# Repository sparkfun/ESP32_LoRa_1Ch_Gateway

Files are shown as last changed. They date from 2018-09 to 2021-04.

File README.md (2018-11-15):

SparkFun LoRa Gateway 1-Channel
========================================

SparkFun LoRa Gateway 1-Channel

[*SparkFun LoRa Gateway 1-Channel (15006)*](https://www.sparkfun.com/products/15006)

A programmable microcontroller featuring both WiFi and Bluetooth radios -- with an RFM95W LoRa transceiver to create a single-channel LoRa gateway. It's a perfect, low-cost tool for monitoring a dozen-or-so LoRa devices, and relaying their messages up to the cloud.

Repository Contents
-------------------

* **/Documentation** - Data sheets, additional product information
* **/Firmware** - Example code 
* **/Hardware** - Eagle design files (.brd, .sch)

Documentation
--------------
* **[Library](https://github.com/sparkfun/ESP32_LoRa_1Ch_Gateway)** - Arduino library for the SparkFun LoRa Gateway 1-Channel.
* **[Hookup Guide](https://learn.sparkfun.com/tutorials/sparkfun-lora-gateway-1-channel-hookup-guide)** - Basic hookup guide for the SparkFun LoRa Gateway 1-Channel.
* **[SparkFun Fritzing repo](https://github.com/sparkfun/Fritzing_Parts)** - Fritzing diagrams for SparkFun products.

Product Versions
----------------
* [15006](https://www.sparkfun.com/products/15006) - SparkFun LoRa Gateway 1-Channel

Version History
---------------
* [v10](https://github.com/sparkfun/ESP32_LoRa_1Ch_Gateway/releases/tag/v10) - Initial redboard release

License Information
-------------------

This product is _**open source**_! 

Please review the LICENSE.md file for license information. 

If you have any questions or concerns on licensing, please contact techsupport@sparkfun.com.

Distributed as-is; no warranty is given.

- Your friends at SparkFun.

_<COLLABORATION CREDIT>_

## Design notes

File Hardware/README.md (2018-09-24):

SparkFun <PRODUCT NAME> Design Files
=====================================

The .sch and .brd files hare are Eagle CAD schematic and PCB design files from SparkFun Electronics.
A freeware version of Eagle can be found [here](http://www.cadsoftusa.com/download-eagle/freeware/).

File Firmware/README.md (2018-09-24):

Software directory contents
===========================

* **ESP-1CH-TTN-Device-ABP** -- Arduino example sketch implementing a single-channel LoRaWAN device with ABP activation.
	* Depends on the [Arduino-LMIC library](https://github.com/mcci-catena/arduino-lmic).
* **arduino-esp32** -- board.txt and pin-variant files to add the SparkX ESP32 LoRa 1-CH Gateway to the ESP32 Arduino core
	* Depends on the [Arduino Core for ESP32 WiFi chip](https://github.com/espressif/arduino-esp32)

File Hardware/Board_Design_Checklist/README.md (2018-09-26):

Design Review Checklist Python Module
=====================================

Original Author: Pete Lewis

Creation Date: 4/9/2015

Updated: 5/10/16

Description:
-------------
This is a little GUI (using Tkinter) intended to make reviewing a board design a bit easier and faster.
I have included the necessary modules and a batch file to make installation easier.
A bunch of helpful images are located [here](https://github.com/sparkfun/Engineering_Design_Rules_Checklist/tree/master/Board_Design_Checklist/doc_images)

Python GUI Installation:
---------------------
### Windows:

1. Install [Python 2.7.x](https://www.python.org/downloads/windows/) on your machine. At the top of this page is a link to the latest release. From there download [Windows x86 MSI installer](https://www.python.org/ftp/python/2.7.11/python-2.7.11.msi).

	1a. Note, It must be installed in the directory "c:\Python27\" for the batch file installation to work.
	
	1b. import _tkinter will fail with: "ImportError: DLL load failed: %1 is not a valid Win32 application." if you try to use the 64-bit version of Python.
2. The installer will give you the option to setup your environment variables. May as well select this. At the time of this writing, it doesn't work right, but it's still helpful.

	2a. Right click on the start menu and select the 'Control Panel'.

	2b. Searching for env will show you 'Edit the system environment variables', choose this.

	2c. Click 'Environment Variables...' at the bottom.

	2d. Double click on 'Path'.

	2e. You should see 'C:\Python27\' & 'C:\Python27\Scripts'. Append a trailing '&#92;' to Scripts to fix it.

2. Clone the [repo](https://github.com/sparkfun/Engineering_Design_Rules_Checklist).
3. Run the batch file named "Install_Modules.bat" from within the repo (Excel_Modules_Installation).
4. You will see a command prompt open up and a bunch of readout.
5. When it's done, you should have the three necessary modules installed.

### OS X:

1. Install Homebrew
	```ruby -e "$(curl -fsSL https://raw.githubusercontent.com/Homebrew/install/master/install)"```
2. Install Python
	```brew install python```
3. Install pip
	```sudo easy_install pip```
4. Install Excel Modules
	```
	sudo pip install xlrd
	
	sudo pip install xlwt
	
	sudo pip install xlutils
	```
5. Clone the [repo](https://github.com/sparkfun/Engineering_Design_Rules_Checklist).
	
### Debian/Ubuntu: 

1. Install Python
	```
	sudo apt-get install python
	```
2. Install Excel Modules
	```
	sudo apt-get install python-xlrd
	
	sudo apt-get install python-xlwt
	
	sudo apt-get install python-pip
	
	sudo pip install xlutils
	```
	
### Generic Install Directions:

1. Install [Python 2.7.x](https://www.python.org/ftp/python/2.7.9/python-2.7.9.msi) on your machine.
2. Download and install the following modules.
  * [XLRD](https://pypi.python.org/pypi/xlrd)
  * [XLWT](https://pypi.python.org/pypi/xlwt)
  * [XLUTILS](https://pypi.python.org/pypi/xlutils)

You can do this with pip, for instance, run the command `pip install xlrd` to install XLRD

Running the Checklist:
----------------------
Run Checklist.py file from a directory that contains the original file `Board_Design_Checklist.xls`, or from a directory that contains an already started product specific `.xls` file.

The python file has two modes of operation:
1. If no `.xls` file exist, the program exits.
2. If an `.xls` file exists and is named `Board_Design_Checklist.xls`, the program will generate a new `.xls` file with the product name appended, such as `Board_Design_Checklist_fancynewproduct_.xls`.  The original spreadsheet is left intact.
3. If there is already a spreadsheet with product name appended, the program will open it for continuation or review.

You can double-click Checklist.py, or run from the command line as `>Checklist.py`

For example, if `folder` contains `Board_Design_Checklist.xls`: 
```
c:\>cd folder

c:\folder>dir
 Directory of c:\folder

06/14/2017  09:31 AM            25,600 Board_Design_Checklist.xls
06/14/2017  09:31 AM            18,827 Checklist.py

c:\folder>Checklist.py
Current User is marshall.taylor
Current Review File is Board_Design_Checklist.xls

c:\folder>dir
 Directory of c:\temp

06/14/2017  09:31 AM            25,600 Board_Design_Checklist.xls
06/15/2017  04:06 PM            22,016 Board_Design_Checklist_fancynewproduct_.xls
06/14/2017  09:31 AM            18,827 Checklist.py

c:\folder>
```

The first screen is a combination of checks. Check all of the boxes that apply to your design. This will help the GUI avoid asking you unnecessary checks.  The name entered here will be appended to the spreadsheet.

The next screens will prompt you all of the questions in the Excel doc (one at a time), and you can click "YES", "NO", "n/a", "back" or "skip".  It will then write to the appropriate cell in the XLS file and put your response (and username).

You can write a comment in the comment box before you click a button, and it will add this comment to your response in the appropriate cell in the Excel doc.

Once you get to the end, click the "Create Summary" button (at the bottom right of the GUI), if you'd like it to create a summary in the form of a text file including all of your responses with comments.

**You must put a comment with any answer if you'd like to it end up in the summary.**

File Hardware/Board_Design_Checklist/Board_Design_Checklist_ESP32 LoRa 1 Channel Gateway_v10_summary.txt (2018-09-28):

1) Have you verified that the BOM in Sparkle is accurate (also checking for PROD_ID, NAME, VALUE, PREFIX)? [NO]
comment: No, I haven't created a sparkle page for this product yet. It will probably be a clone of the SparkX version. 

2) Is the I2C address in the schematic? [n/a]
comment: N/A - this is an I2C master

3) Is the I2C pin order correct (GND/VCC/SDA/CLK) and did you consider using a Qwiic connector? [YES]
comment: Qwiic connector used

4) Is the I2C pull-up resistor isolation jumper present? [NO]
comment: No, this is a master. All downstream devices will have isolation option. Discussed with Nate

5) Is the SPI pull-up resistor for Chip Select present? [NO]
comment: No. There could be a CS PU on the RFM_CS net but this board is so jam-packed and that line is not broken out so I'm comfortable leaving it up to the ESP to push/pull that line

6) Are active low pins labeled clearly? [NO]
comment: RST is not, but this board is very tight

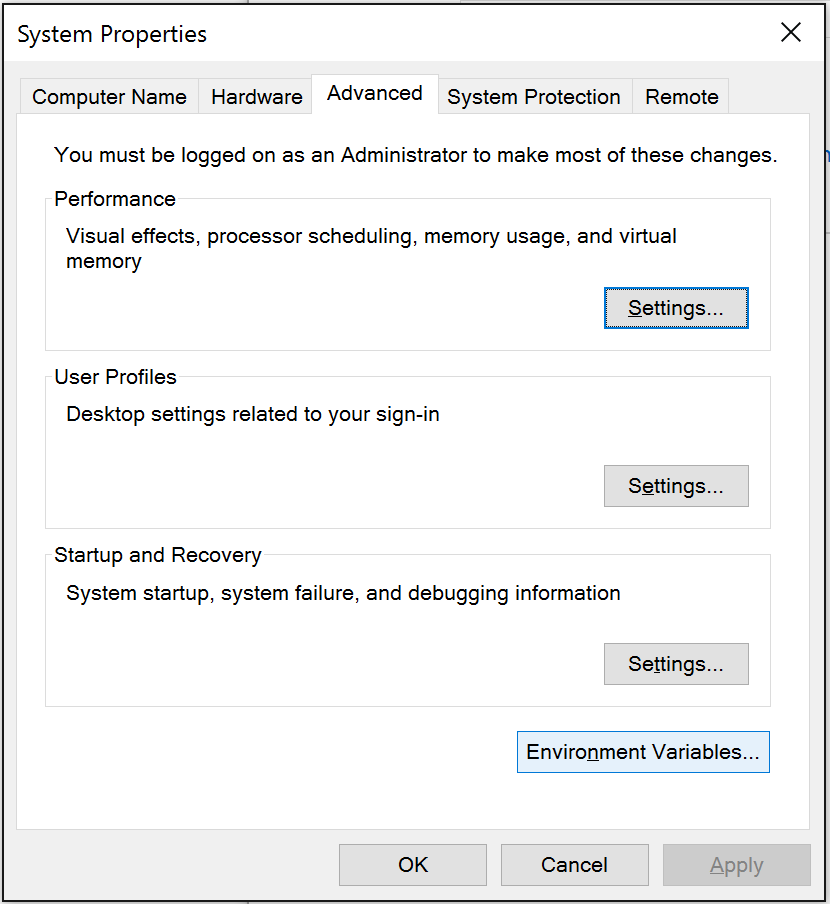
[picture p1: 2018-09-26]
Hardware/Board_Design_Checklist/doc_images/07-env_variables.png

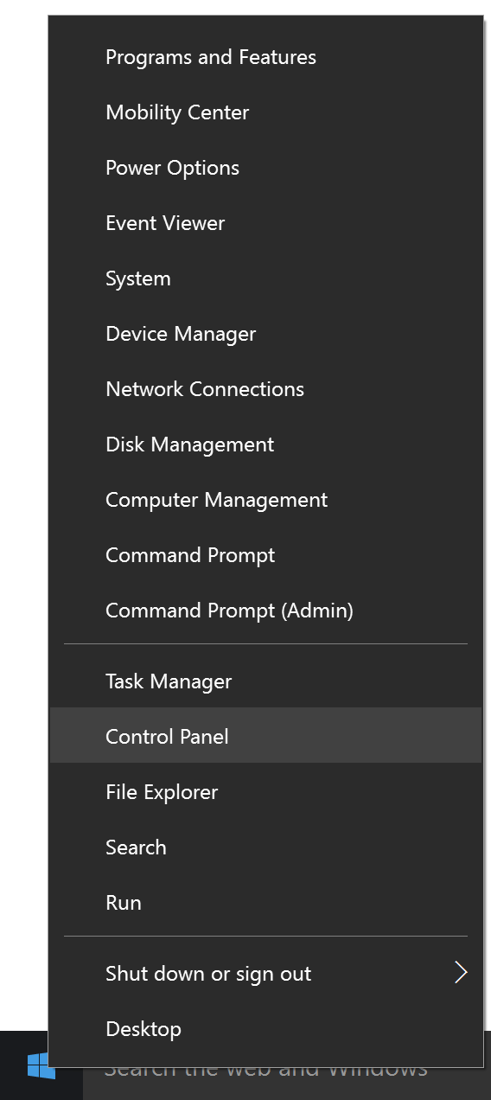
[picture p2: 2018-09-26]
Hardware/Board_Design_Checklist/doc_images/05-control_panel.png

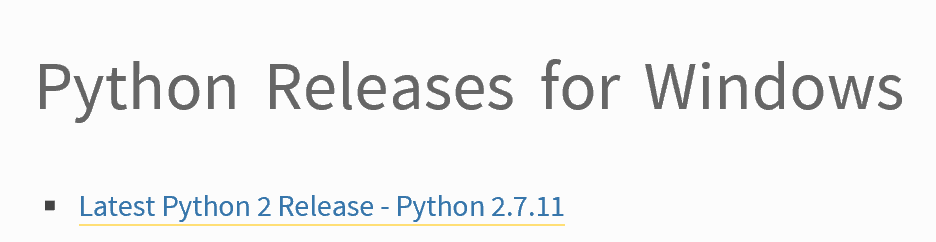
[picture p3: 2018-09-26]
Hardware/Board_Design_Checklist/doc_images/01-link.png

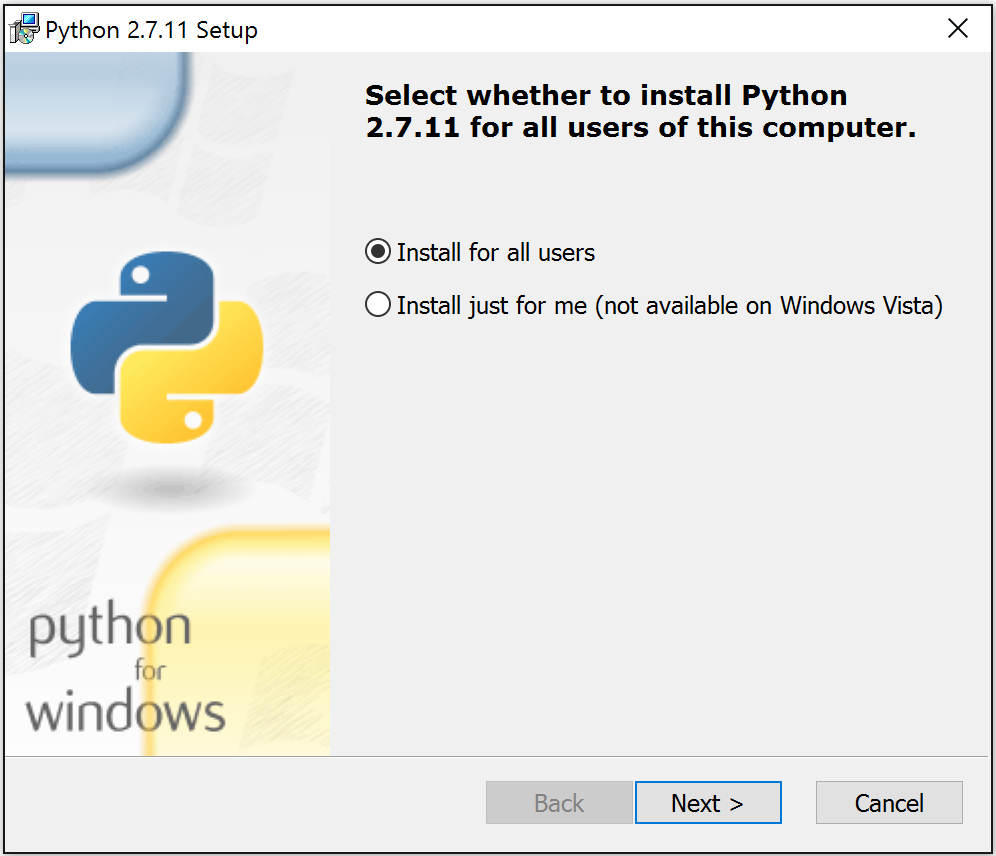
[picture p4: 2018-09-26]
Hardware/Board_Design_Checklist/doc_images/02-who.png

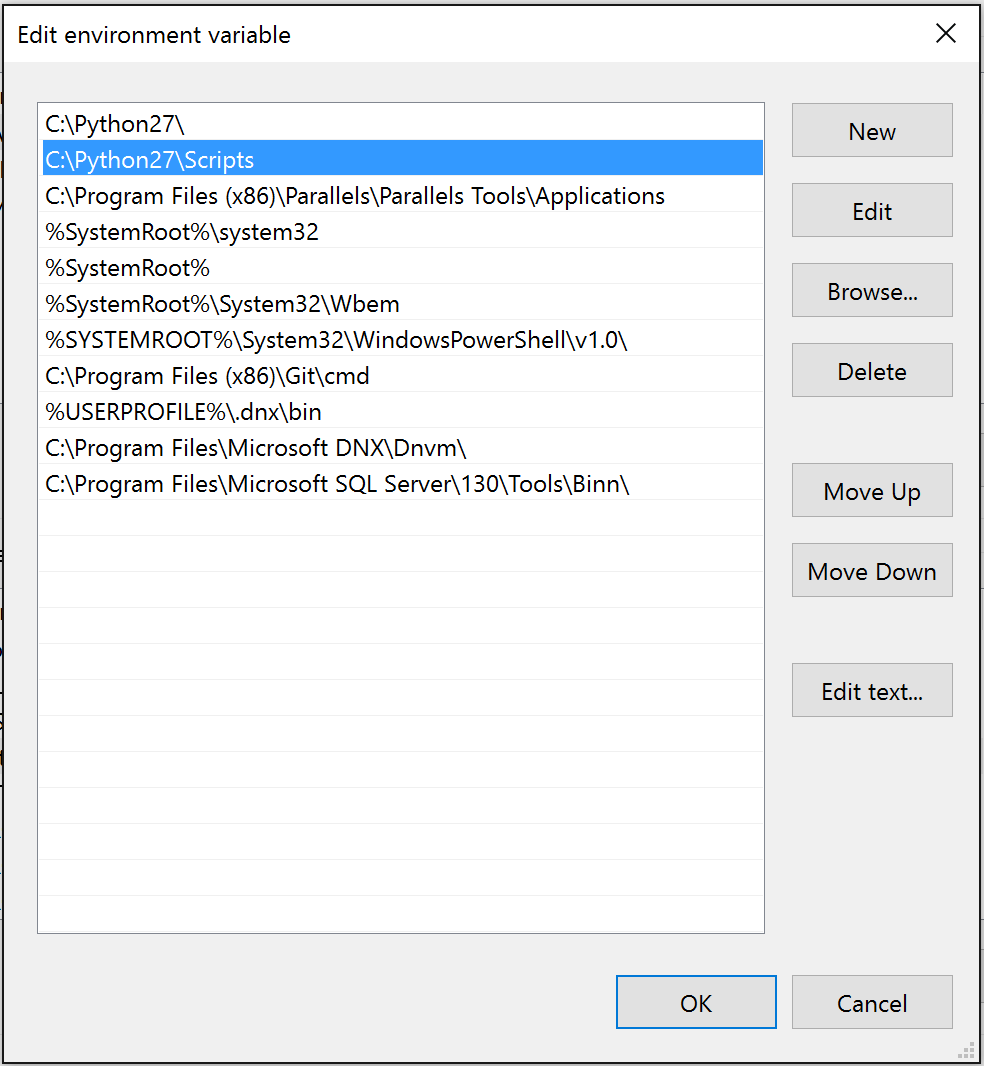
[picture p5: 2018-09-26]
Hardware/Board_Design_Checklist/doc_images/09-bad_path.png

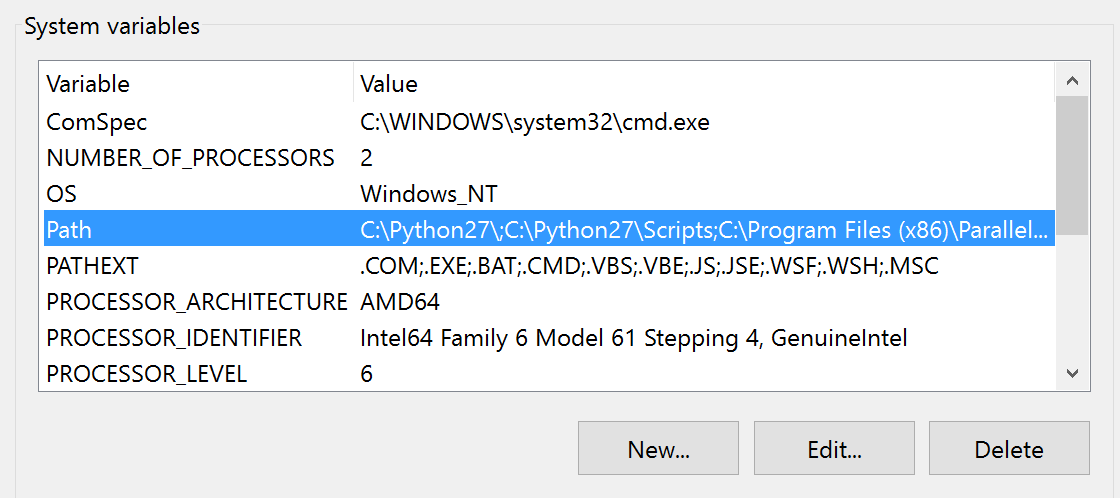
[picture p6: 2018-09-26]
Hardware/Board_Design_Checklist/doc_images/08-path.png

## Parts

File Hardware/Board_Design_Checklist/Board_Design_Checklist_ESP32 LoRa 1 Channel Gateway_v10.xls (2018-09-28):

SECTION | CHECK | STATUS | DEPENDANCY | CORRECT ANSWER | USER | USER-ANSWER | COMMENT | WIKI_LINK
Macro | is_revision | 0
Macro | has_pth | 1
Macro | has_i2c | 1
Macro | has_SPI | 1
Macro | has_1x6_ftdi_header | 0
Macro | has_jumpers | 1
Macro | has_leds | 1
Macro | has_vreg | 1
Macro | has_QFN | 0
Macro | has_SS | 0
Macro | has_multi_sheet | 0
Macro | is_kit | 0
Macro | has_serial | 0
Macro | is_4layer | 0
Macro | has_milling | 1
Macro | has_switchorbutton | 1
Macro | has_collaboration | 1
General | Are the part libraries consistent with eagle github repo? |  |  | YES | owen.lyke | YES
Schematic | Is the proper frame with CC attribution used? |  |  | YES | owen.lyke | YES
Schematic | Are all schematic objects inside the frame? |  |  | YES | owen.lyke | YES
Schematic | Is there a SparkFun Logo? |  |  | YES | owen.lyke | YES
Schematic | Is there an OSHW logo? |  |  | YES | owen.lyke | YES
Schematic | Is proper attribution given to the original designer? |  |  | YES | owen.lyke | YES
Schematic | Is "Revised by: " and the reviser's name present? |  | 2 | YES | owen.lyke | *n/a*
Schematic | Are NET labels the correct FLAG type? |  |  | YES | owen.lyke | YES
Schematic | Have all nets been drawn straight out from pin connections at least one grid space? |  |  | YES | owen.lyke | YES
Schematic | Are all net lines 0.006 inch? |  |  | YES | owen.lyke | YES
Schematic | Are there any 4-way junctions? |  |  | NO | owen.lyke | NO
Schematic | Are junction dots used for all 3-wire connections? |  |  | YES | owen.lyke | YES
Schematic | Are the fiducials in the lower right corner? |  |  | YES | owen.lyke | YES
Schematic | Are the standoffs in the lower right corner? |  |  | YES | owen.lyke | YES
Schematic | Are dashed grey lines ('info' eagle layer 97) used to clearly separate different areas? |  |  | YES | owen.lyke | YES
Schematic | Is the version number correct? |  |  | YES | owen.lyke | YES
Schematic | Is the version number included on all sheets? |  | 12 | YES | owen.lyke | *n/a*
Schematic | Do all GND connections use the GND symbol (oriented downward)? |  |  | YES | owen.lyke | YES
Schematic | Do all VCC connections use the VCC symbol (oriented upward)? |  |  | YES | owen.lyke | YES
Schematic | Is the VCC range clearly labeled? |  |  | YES | owen.lyke | YES
Schematic | Are any jumpers labeled clearly by their function and possible settings? |  | 7 | YES | owen.lyke | YES
Schematic | Are any appropriate warnings (voltage conversion, sensitive I/O) labeled? |  |  | YES | owen.lyke | n/a
Schematic | Are any notes of two versions of the board in the schematic (3.3V regulator vs 5V regulator)? |  |  | YES | owen.lyke | n/a
Schematic | Do any part names have '/.~' in them? (Multiple sheets) |  | 12 | NO | owen.lyke | *n/a*
Schematic | Have you verified that the BOM in Sparkle is accurate (also checking for PROD_ID, NAME, VALUE, PREFIX)? |  |  | YES | owen.lyke | NO | No, I haven't created a sparkle page for this product yet. It will probably be a clone of the SparkX version.
Schematic | Do any parts have unnecessary values (Eagle has autoset the package as the value)? |  |  | NO | owen.lyke | NO
Schematic | Regarding the voltage regulator, is the input on the LEFT, and the output on the RIGHT? |  | 9 | YES | owen.lyke | YES
Schematic | Is the I2C address in the schematic? |  | 4 | YES | owen.lyke | n/a | N/A - this is an I2C master
Schematic | Is the I2C pin order correct (GND/VCC/SDA/CLK) and did you consider using a Qwiic connector? |  | 4 | YES | owen.lyke | YES | Qwiic connector used | https://wiki.sparkfun.com/index.php?title=Eagle_Rules#Pin_Out.2FConnection_Orientation
Schematic | Is the I2C pull-up resistor isolation jumper present? |  | 4 | YES | owen.lyke | NO | No, this is a master. All downstream devices will have isolation option. Discussed with Nate | https://wiki.sparkfun.com/index.php?title=Eagle_Rules#Component_Placement
Schematic | Is the SPI pull-up resistor for Chip Select present? |  | 5 | YES | owen.lyke | NO | No. There could be a CS PU on the RFM_CS net but this board is so jam-packed and that line is not broken out so I'm comfortable leaving it up to the ESP to push/pull that line | https://wiki.sparkfun.com/index.php?title=Eagle_Rules#Component_Placement
Schematic | Is the MISO tri-state buffer included? |  | 5 | YES | owen.lyke | NO |  | https://wiki.sparkfun.com/index.php?title=Eagle_Rules#Component_Placement
Board | If this is a Qwiic board, does it follow the design guidelines for Qwiic boards in the Wiki? |  | 4 | YES | owen.lyke | n/a |  | https://wiki.sparkfun.com/index.php?title=Qwiic_Standard
Board | If this board is not branded as a Qwicc board, but contains a Qwiic connector, is the connector labeled with “QWIIC” text silk? |  | 4 |  | owen.lyke | YES
Board | Are the inner layers on the correct eagle layers? (2 and 15) |  | 15 | YES | owen.lyke | *n/a* |  | https://wiki.sparkfun.com/index.php?title=Eagle_Rules#Board_Creation.2C_Outline
Board | Does your 4 layer board include '1' '2' '3' '4' in the copper of each layer? |  | 15 | YES | owen.lyke | *n/a* |  | https://wiki.sparkfun.com/index.php?title=Eagle_Rules#Board_Creation.2C_Outline
Board | Is the bottom left corner board dimensions at 0,0? |  |  | YES | owen.lyke | YES |  | https://wiki.sparkfun.com/index.php?title=Eagle_Rules#Board_Creation.2C_Outline
Board | Is the board dimension outline correct thickness? (0.008 inch) |  |  | YES | owen.lyke | YES |  | https://wiki.sparkfun.com/index.php?title=Eagle_Rules#Board_Creation.2C_Outline
Board | If this requires very precise dimensions (e.g. USB stick), did you consider GP's tolerances? (dimension=5mils, Vscore=10mils) |  |  |  | owen.lyke | n/a |  | https://wiki.sparkfun.com/index.php?title=Eagle_Rules#Fab_house_Tolerances
Board | Are 0.1 inch headers lined up on 0.1 inch grid? |  |  | YES | owen.lyke | YES |  | https://wiki.sparkfun.com/index.php?title=Eagle_Rules#Board_Creation.2C_Outline
Board | Are opposing 0.1 inch headers spaced to fit into a breadboard? |  |  | YES | owen.lyke | YES |  | https://wiki.sparkfun.com/index.php?title=Eagle_Rules#Board_Creation.2C_Outline
Board | Do all testpoints have a separation of at least 0.1 inch (preferably placed on a 0.05 inch grid)? |  |  | YES | owen.lyke | n/a |  | https://wiki.sparkfun.com/index.php?title=Eagle_Rules#Board_Creation.2C_Outline
Board | Does the board have standoffs? |  |  | YES | owen.lyke | NO |  | https://wiki.sparkfun.com/index.php?title=Eagle_Rules#Board_Creation.2C_Outline
Board | Can standoffs/screws be used clear of other parts? |  |  | YES | owen.lyke | n/a |  | https://wiki.sparkfun.com/index.php?title=Eagle_Rules#Board_Creation.2C_Outline
Board | Is the FTDI connector accessible (do neighboring parts allow enough space to clear each side)? |  | 6 | YES | owen.lyke | *n/a* |  | https://wiki.sparkfun.com/index.php?title=Eagle_Rules#Pin_Out.2FConnection_Orientation
Board | Is the FTDI connector oriented so the FTDI breakout can be slid on properly (IC side up, header side down)? |  | 6 | YES | owen.lyke | *n/a* |  | https://wiki.sparkfun.com/index.php?title=Eagle_Rules#Pin_Out.2FConnection_Orientation
Board | Are vias tented correctly? |  |  | YES | owen.lyke | YES |  | https://wiki.sparkfun.com/index.php?title=Eagle_Rules#Trace_Routing.2C_Polygon_Pours.2C_and_Vias
Board | If possible, are all overhanging parts on the same edge of the board (this helps with panelization)? |  |  | YES | owen.lyke | YES |  | https://wiki.sparkfun.com/index.php?title=Eagle_Rules#Pin_Out.2FConnection_Orientation
Board | If this design requires special ordering or production assembly instructions, have the symbols/packages been added with notes? (PCB thickness, humidity sensitivity, etc.) |  |  | YES | owen.lyke | n/a
Board | Are any vias intended to be used as PTH headers (they shouldn't be)? |  |  | NO | owen.lyke | NO |  | https://wiki.sparkfun.com/index.php?title=Eagle_Rules#Trace_Routing.2C_Polygon_Pours.2C_and_Vias
Board | Is the LED color standard followed? (red for power, blue for STAT, green for TX, yellow for RX) |  | 8 | YES | owen.lyke | YES |  | https://wiki.sparkfun.com/index.php?title=Eagle_Rules#Component_Placement
Board | Do parts that need selective solder have a planned nozzle path on layer 48? (valid widths: 0.178", 0,263", 0.354") |  | 11 | YES | owen.lyke | *n/a* |  | https://wiki.sparkfun.com/index.php?title=Eagle_Rules#Selective_Soldering
Board | As best as possible, do all SMD pads have only 1 trace entering the pad? |  |  | YES | owen.lyke | YES |  | https://wiki.sparkfun.com/index.php?title=Eagle_Rules#PCB_Layout
Board | Are there any natural bridges on SMT components? |  |  | NO | owen.lyke | NO |  | https://wiki.sparkfun.com/index.php?title=Eagle_Rules#PCB_Layout
Board | Do V-Scored edges have a 50 mil border free of pads and parts (to prevent cracking on separation)? |  |  | YES | owen.lyke | NO
Board | Is the direction of TX/RX serial connections correct? |  | 14 | YES | owen.lyke | *n/a*
Board | Are the TX/RX pins of the FTDI properly connected? |  | 6 | YES | owen.lyke | *n/a*
Board | Is trace routing up to spec? (to/from center-points, straight lines, 45 angles, 'T' intersections, no right angles or acid traps) |  |  | YES | owen.lyke | YES |  | https://wiki.sparkfun.com/index.php?title=Eagle_Rules#PCB_Layout
Board | For thermal considerations, are traces routed away from the component, with symmetrical routing? |  | 10 | YES | owen.lyke | *n/a*
Board | Do all footprints pass 1:1 check? (Applies mostly to new components) |  |  | YES | owen.lyke | YES
Board | Are all QFN components with 6 or more leads 75 percent pasted on lead pads? (May be contended depending on performance) |  | 10 | YES | owen.lyke | *n/a* |  | https://wiki.sparkfun.com/index.php?title=Eagle_Rules#Footprints.2FPackages
Board | Are center pad cream apertures properly reduced? (50-75% paste is good) |  | 10 | YES | owen.lyke | *n/a* |  | https://wiki.sparkfun.com/index.php?title=Eagle_Rules#Footprints.2FPackages
Board | Is there solder mask between pads on of 11 mil separation and greater? |  |  | YES | owen.lyke | YES |  | https://wiki.sparkfun.com/index.php?title=Eagle_Rules#Fab_house_Tolerances
Board | Is there a correct version number in the copper (aligned properly with the edge of the PCB)? |  |  | YES | owen.lyke | YES
Board | Are there fiducials on both the TOP and BOTTOM of the board? |  |  | YES | owen.lyke | YES
Board | Does it pass DRC with top/bottom keepout layers on? |  |  | YES | owen.lyke | YES
Board | If there are any DRC errors, have they all been approved? |  |  | YES | owen.lyke | YES
Board | Are there airwires after ratsnest? |  |  | NO | owen.lyke | NO
Board | Are all KIT PTH parts on the correct side with correct masking (e.g. the TSTOP or BSTOP expose the correct side) |  | 13 | YES | owen.lyke | *n/a*
Documentation | Is there a note for a 4-layer board (on tDOCU)? |  | 15 | YES | owen.lyke | *n/a*
Documentation | Do all packages have NAME and VALUE? |  |  | YES | owen.lyke | YES
Documentation | Is there a note for a board thickness other than 0.63 inch? |  |  |  | owen.lyke | n/a
Documentation | Are measurements included for outer dimension and standoffs (Eagle layer 47)? |  |  | YES | owen.lyke | YES
Documentation | Are the board dimensions on 0.05 inch or 0.01 inch grid? |  |  | YES | owen.lyke | YES
Documentation | Are routed-out areas labeled 'ROUTE OUT' (on dimension)? |  | 16 | YES | owen.lyke | n/a
Documentation | Is the CC/Design By included in tDocu? |  |  | YES | owen.lyke | YES
Documentation | Is the designer name included in tDocu? |  |  | YES | owen.lyke | YES
Documentation | Is 'Revised by:' and 'Revisor Name' included in tDocu? |  | 2 | YES | owen.lyke | *n/a*
Silkscreen/Labeling | Is the name of the board on the board? |  |  | YES | owen.lyke | YES |  | https://wiki.sparkfun.com/index.php?title=Eagle_Rules#PCB_Silk
Silkscreen/Labeling | Do all footprints have 0.008 inch silk footprint? |  |  | YES | owen.lyke | YES
Silkscreen/Labeling | Are all LEDs labeled with their purpose? |  | 8 | YES | owen.lyke | YES
Silkscreen/Labeling | Are all PTHs (aka connectors) clearly labeled with their purpose on both sides of the board? |  |  | YES | owen.lyke | YES
Silkscreen/Labeling | Are battery terminals labeled +/- correctly? |  |  | YES | owen.lyke | n/a
Silkscreen/Labeling | Are all jumpers labeled? |  | 7 | YES | owen.lyke | YES
Silkscreen/Labeling | If it is a 3-way jumper, is there a label on each side of the jumper? |  | 7 | YES | owen.lyke | n/a
Silkscreen/Labeling | Are all switches/buttons labeled properly? |  | 17 | YES | owen.lyke | YES
Silkscreen/Labeling | Are active low pins labeled clearly? |  |  | YES | owen.lyke | NO | RST is not, but this board is very tight
Silkscreen/Labeling | Are all labels lined up properly? |  |  | YES | owen.lyke | YES
Silkscreen/Labeling | Is all text at least 0.032 inch, 15 percent radio, and vector? |  |  | YES | owen.lyke | YES
Silkscreen/Labeling | Does the FTDI connector have BLK/GRN labeled correctly? |  | 6 | YES | owen.lyke | *n/a*
Silkscreen/Labeling | Do all components have polarity or pin 1 labeled? |  |  | YES | owen.lyke | YES
Silkscreen/Labeling | Is the polarity label outside of the package for visibility after part population? |  |  | YES | owen.lyke | YES
Silkscreen/Labeling | Are there check labels for different versions of the board (3.3V vs 5V)? |  |  | YES | owen.lyke | n/a
Silkscreen/Labeling | Is the SparkFun Logo on the board? |  |  | YES | owen.lyke | YES
Silkscreen/Labeling | Is the OSHW logo on the board? |  |  | YES | owen.lyke | YES
Silkscreen/Labeling | Is the firmware opensource? If not, did you omit the OSHW Logo? |  | 18 | YES | owen.lyke | YES
Silkscreen/Labeling | Is any silkscreen overlaid on vias? |  |  | NO | owen.lyke | NO
Silkscreen/Labeling | Is there a URL for any kits or unique boards? |  |  |  | owen.lyke | n/a
Special | Are dimension lines properly spaced for V-scoring (lines on a 0.020” center-to-center spacing)? |  |  |  | owen.lyke | n/a
Special | On white solder mask pcbs, is there any solder mask between leads on large SMT components? |  |  |  | owen.lyke | n/a
Special | Are axes labeled correctly? |  |  |  | owen.lyke | n/a
Special | Are there warning labels for high voltage areas? |  |  |  | owen.lyke | n/a
END | Thanks for flying with us. Have a great day!! |  |  |  | owen.lyke | YES

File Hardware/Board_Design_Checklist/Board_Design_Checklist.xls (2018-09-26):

SECTION | CHECK | STATUS | DEPENDANCY | CORRECT ANSWER | USER | USER-ANSWER | COMMENT | WIKI_LINK
Macro | is_revision | 0
Macro | has_pth | 0
Macro | has_i2c | 0
Macro | has_SPI | 0
Macro | has_1x6_ftdi_header | 0
Macro | has_jumpers | 0
Macro | has_leds | 0
Macro | has_vreg | 0
Macro | has_QFN | 0
Macro | has_SS | 0
Macro | has_multi_sheet | 0
Macro | is_kit | 0
Macro | has_serial | 0
Macro | is_4layer | 0
Macro | has_milling | 0
Macro | has_switchorbutton | 0
Macro | has_collaboration | 0
General | Are the part libraries consistent with eagle github repo? |  |  | YES
Schematic | Is the proper frame with CC attribution used? |  |  | YES
Schematic | Are all schematic objects inside the frame? |  |  | YES
Schematic | Is there a SparkFun Logo? |  |  | YES
Schematic | Is there an OSHW logo? |  |  | YES
Schematic | Is proper attribution given to the original designer? |  |  | YES
Schematic | Is "Revised by: " and the reviser's name present? |  | 2 | YES
Schematic | Are NET labels the correct FLAG type? |  |  | YES
Schematic | Have all nets been drawn straight out from pin connections at least one grid space? |  |  | YES
Schematic | Are all net lines 0.006 inch? |  |  | YES
Schematic | Are there any 4-way junctions? |  |  | NO
Schematic | Are junction dots used for all 3-wire connections? |  |  | YES
Schematic | Are the fiducials in the lower right corner? |  |  | YES
Schematic | Are the standoffs in the lower right corner? |  |  | YES
Schematic | Are dashed grey lines ('info' eagle layer 97) used to clearly separate different areas? |  |  | YES
Schematic | Is the version number correct? |  |  | YES
Schematic | Is the version number included on all sheets? |  | 12 | YES
Schematic | Do all GND connections use the GND symbol (oriented downward)? |  |  | YES
Schematic | Do all VCC connections use the VCC symbol (oriented upward)? |  |  | YES
Schematic | Is the VCC range clearly labeled? |  |  | YES
Schematic | Are any jumpers labeled clearly by their function and possible settings? |  | 7 | YES
Schematic | Are any appropriate warnings (voltage conversion, sensitive I/O) labeled? |  |  | YES
Schematic | Are any notes of two versions of the board in the schematic (3.3V regulator vs 5V regulator)? |  |  | YES
Schematic | Do any part names have '/.~' in them? (Multiple sheets) |  | 12 | NO
Schematic | Have you verified that the BOM in Sparkle is accurate (also checking for PROD_ID, NAME, VALUE, PREFIX)? |  |  | YES
Schematic | Do any parts have unnecessary values (Eagle has autoset the package as the value)? |  |  | NO
Schematic | Regarding the voltage regulator, is the input on the LEFT, and the output on the RIGHT? |  | 9 | YES
Schematic | Is the I2C address in the schematic? |  | 4 | YES
Schematic | Is the I2C pin order correct (GND/VCC/SDA/CLK) and did you consider using a Qwiic connector? |  | 4 | YES |  |  |  | https://wiki.sparkfun.com/index.php?title=Eagle_Rules#Pin_Out.2FConnection_Orientation
Schematic | Is the I2C pull-up resistor isolation jumper present? |  | 4 | YES |  |  |  | https://wiki.sparkfun.com/index.php?title=Eagle_Rules#Component_Placement
Schematic | Is the SPI pull-up resistor for Chip Select present? |  | 5 | YES |  |  |  | https://wiki.sparkfun.com/index.php?title=Eagle_Rules#Component_Placement
Schematic | Is the MISO tri-state buffer included? |  | 5 | YES |  |  |  | https://wiki.sparkfun.com/index.php?title=Eagle_Rules#Component_Placement
Board | If this is a Qwiic board, does it follow the design guidelines for Qwiic boards in the Wiki? |  | 4 | YES |  |  |  | https://wiki.sparkfun.com/index.php?title=Qwiic_Standard
Board | If this board is not branded as a Qwicc board, but contains a Qwiic connector, is the connector labeled with “QWIIC” text silk? |  | 4
Board | Are the inner layers on the correct eagle layers? (2 and 15) |  | 15 | YES |  |  |  | https://wiki.sparkfun.com/index.php?title=Eagle_Rules#Board_Creation.2C_Outline
Board | Does your 4 layer board include '1' '2' '3' '4' in the copper of each layer? |  | 15 | YES |  |  |  | https://wiki.sparkfun.com/index.php?title=Eagle_Rules#Board_Creation.2C_Outline
Board | Is the bottom left corner board dimensions at 0,0? |  |  | YES |  |  |  | https://wiki.sparkfun.com/index.php?title=Eagle_Rules#Board_Creation.2C_Outline
Board | Is the board dimension outline correct thickness? (0.008 inch) |  |  | YES |  |  |  | https://wiki.sparkfun.com/index.php?title=Eagle_Rules#Board_Creation.2C_Outline
Board | If this requires very precise dimensions (e.g. USB stick), did you consider GP's tolerances? (dimension=5mils, Vscore=10mils) |  |  |  |  |  |  | https://wiki.sparkfun.com/index.php?title=Eagle_Rules#Fab_house_Tolerances
Board | Are 0.1 inch headers lined up on 0.1 inch grid? |  |  | YES |  |  |  | https://wiki.sparkfun.com/index.php?title=Eagle_Rules#Board_Creation.2C_Outline
Board | Are opposing 0.1 inch headers spaced to fit into a breadboard? |  |  | YES |  |  |  | https://wiki.sparkfun.com/index.php?title=Eagle_Rules#Board_Creation.2C_Outline
Board | Do all testpoints have a separation of at least 0.1 inch (preferably placed on a 0.05 inch grid)? |  |  | YES |  |  |  | https://wiki.sparkfun.com/index.php?title=Eagle_Rules#Board_Creation.2C_Outline
Board | Does the board have standoffs? |  |  | YES |  |  |  | https://wiki.sparkfun.com/index.php?title=Eagle_Rules#Board_Creation.2C_Outline
Board | Can standoffs/screws be used clear of other parts? |  |  | YES |  |  |  | https://wiki.sparkfun.com/index.php?title=Eagle_Rules#Board_Creation.2C_Outline
Board | Is the FTDI connector accessible (do neighboring parts allow enough space to clear each side)? |  | 6 | YES |  |  |  | https://wiki.sparkfun.com/index.php?title=Eagle_Rules#Pin_Out.2FConnection_Orientation
Board | Is the FTDI connector oriented so the FTDI breakout can be slid on properly (IC side up, header side down)? |  | 6 | YES |  |  |  | https://wiki.sparkfun.com/index.php?title=Eagle_Rules#Pin_Out.2FConnection_Orientation
Board | Are vias tented correctly? |  |  | YES |  |  |  | https://wiki.sparkfun.com/index.php?title=Eagle_Rules#Trace_Routing.2C_Polygon_Pours.2C_and_Vias
Board | If possible, are all overhanging parts on the same edge of the board (this helps with panelization)? |  |  | YES |  |  |  | https://wiki.sparkfun.com/index.php?title=Eagle_Rules#Pin_Out.2FConnection_Orientation
Board | If this design requires special ordering or production assembly instructions, have the symbols/packages been added with notes? (PCB thickness, humidity sensitivity, etc.) |  |  | YES
Board | Are any vias intended to be used as PTH headers (they shouldn't be)? |  |  | NO |  |  |  | https://wiki.sparkfun.com/index.php?title=Eagle_Rules#Trace_Routing.2C_Polygon_Pours.2C_and_Vias
Board | Is the LED color standard followed? (red for power, blue for STAT, green for TX, yellow for RX) |  | 8 | YES |  |  |  | https://wiki.sparkfun.com/index.php?title=Eagle_Rules#Component_Placement
Board | Do parts that need selective solder have a planned nozzle path on layer 48? (valid widths: 0.178", 0,263", 0.354") |  | 11 | YES |  |  |  | https://wiki.sparkfun.com/index.php?title=Eagle_Rules#Selective_Soldering
Board | As best as possible, do all SMD pads have only 1 trace entering the pad? |  |  | YES |  |  |  | https://wiki.sparkfun.com/index.php?title=Eagle_Rules#PCB_Layout
Board | Are there any natural bridges on SMT components? |  |  | NO |  |  |  | https://wiki.sparkfun.com/index.php?title=Eagle_Rules#PCB_Layout
Board | Do V-Scored edges have a 50 mil border free of pads and parts (to prevent cracking on separation)? |  |  | YES
Board | Is the direction of TX/RX serial connections correct? |  | 14 | YES
Board | Are the TX/RX pins of the FTDI properly connected? |  | 6 | YES
Board | Is trace routing up to spec? (to/from center-points, straight lines, 45 angles, 'T' intersections, no right angles or acid traps) |  |  | YES |  |  |  | https://wiki.sparkfun.com/index.php?title=Eagle_Rules#PCB_Layout
Board | For thermal considerations, are traces routed away from the component, with symmetrical routing? |  | 10 | YES
Board | Do all footprints pass 1:1 check? (Applies mostly to new components) |  |  | YES
Board | Are all QFN components with 6 or more leads 75 percent pasted on lead pads? (May be contended depending on performance) |  | 10 | YES |  |  |  | https://wiki.sparkfun.com/index.php?title=Eagle_Rules#Footprints.2FPackages
Board | Are center pad cream apertures properly reduced? (50-75% paste is good) |  | 10 | YES |  |  |  | https://wiki.sparkfun.com/index.php?title=Eagle_Rules#Footprints.2FPackages
Board | Is there solder mask between pads on of 11 mil separation and greater? |  |  | YES |  |  |  | https://wiki.sparkfun.com/index.php?title=Eagle_Rules#Fab_house_Tolerances
Board | Is there a correct version number in the copper (aligned properly with the edge of the PCB)? |  |  | YES
Board | Are there fiducials on both the TOP and BOTTOM of the board? |  |  | YES
Board | Does it pass DRC with top/bottom keepout layers on? |  |  | YES
Board | If there are any DRC errors, have they all been approved? |  |  | YES
Board | Are there airwires after ratsnest? |  |  | NO
Board | Are all KIT PTH parts on the correct side with correct masking (e.g. the TSTOP or BSTOP expose the correct side) |  | 13 | YES
Documentation | Is there a note for a 4-layer board (on tDOCU)? |  | 15 | YES
Documentation | Do all packages have NAME and VALUE? |  |  | YES
Documentation | Is there a note for a board thickness other than 0.63 inch?
Documentation | Are measurements included for outer dimension and standoffs (Eagle layer 47)? |  |  | YES
Documentation | Are the board dimensions on 0.05 inch or 0.01 inch grid? |  |  | YES
Documentation | Are routed-out areas labeled 'ROUTE OUT' (on dimension)? |  | 16 | YES
Documentation | Is the CC/Design By included in tDocu? |  |  | YES
Documentation | Is the designer name included in tDocu? |  |  | YES
Documentation | Is 'Revised by:' and 'Revisor Name' included in tDocu? |  | 2 | YES
Silkscreen/Labeling | Is the name of the board on the board? |  |  | YES |  |  |  | https://wiki.sparkfun.com/index.php?title=Eagle_Rules#PCB_Silk
Silkscreen/Labeling | Do all footprints have 0.008 inch silk footprint? |  |  | YES
Silkscreen/Labeling | Are all LEDs labeled with their purpose? |  | 8 | YES
Silkscreen/Labeling | Are all PTHs (aka connectors) clearly labeled with their purpose on both sides of the board? |  |  | YES
Silkscreen/Labeling | Are battery terminals labeled +/- correctly? |  |  | YES
Silkscreen/Labeling | Are all jumpers labeled? |  | 7 | YES
Silkscreen/Labeling | If it is a 3-way jumper, is there a label on each side of the jumper? |  | 7 | YES
Silkscreen/Labeling | Are all switches/buttons labeled properly? |  | 17 | YES
Silkscreen/Labeling | Are active low pins labeled clearly? |  |  | YES
Silkscreen/Labeling | Are all labels lined up properly? |  |  | YES
Silkscreen/Labeling | Is all text at least 0.032 inch, 15 percent radio, and vector? |  |  | YES
Silkscreen/Labeling | Does the FTDI connector have BLK/GRN labeled correctly? |  | 6 | YES
Silkscreen/Labeling | Do all components have polarity or pin 1 labeled? |  |  | YES
Silkscreen/Labeling | Is the polarity label outside of the package for visibility after part population? |  |  | YES
Silkscreen/Labeling | Are there check labels for different versions of the board (3.3V vs 5V)? |  |  | YES
Silkscreen/Labeling | Is the SparkFun Logo on the board? |  |  | YES
Silkscreen/Labeling | Is the OSHW logo on the board? |  |  | YES
Silkscreen/Labeling | Is the firmware opensource? If not, did you omit the OSHW Logo? |  | 18 | YES
Silkscreen/Labeling | Is any silkscreen overlaid on vias? |  |  | NO
Silkscreen/Labeling | Is there a URL for any kits or unique boards?
Special | Are dimension lines properly spaced for V-scoring (lines on a 0.020” center-to-center spacing)?
Special | On white solder mask pcbs, is there any solder mask between leads on large SMT components?
Special | Are axes labeled correctly?
Special | Are there warning labels for high voltage areas?
END | Thanks for flying with us. Have a great day!!

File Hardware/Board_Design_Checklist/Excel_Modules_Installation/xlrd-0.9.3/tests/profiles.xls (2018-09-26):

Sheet: PROFILEDEF
PROFIL | a | b | c | d | e | f | g | h | i | j | k | l
P8.2 | 100 | 101 | 102 | 103 | 104 | 105 | 106 | 107 | 108 | 109 | 110 | 111
P8.3 | 112 | 113 | 114 | 115 | 116 | 117 | 118 | 119 | 120 | 121 | 122 | 123
P8.4 | 124 | 125 | 126 | 127 | 128 | 129 | 130 | 131 | 132 | 133 | 134 | 135
P8.5 | 136 | 137 | 138 | 139 | 140 | 141 | 142 | 143 | 144 | 145 | 146 | 147
P8.6 | 148 | 149 | 150 | 151 | 152 | 153 | 154 | 155 | 156 | 157 | 158 | 159
P8.7 | 160 | 161 | 162 | 163 | 164 | 165 | 166 | 167 | 168 | 169 | 170 | 171
P9 | 172 | 173 | 174 | 175 | 176 | 177 | 178 | 179 | 180 | 181 | 182 | 183
P9.1 | 184 | 185 | 186 | 187 | 188 | 189 | 190 | 191 | 192 | 193 | 194 | 195
P9.2 | 196 | 197 | 198 | 199 | 200 | 201 | 202 | 203 | 204 | 205 | 206 | 207
P9.3 | 208 | 209 | 210 | 211 | 212 | 213 | 214 | 215 | 216 | 217 | 218 | 219
P9.4 | 220 | 221 | 222 | 223 | 224 | 225 | 226 | 227 | 228 | 229 | 230 | 231
P9.5 | 232 | 233 | 234 | 235 | 236 | 237 | 238 | 239 | 240 | 241 | 242 | 243
P9.6 | 244 | 245 | 246 | 247 | 248 | 249 | 250 | 251 | 252 | 253 | 254 | 255
Q0 | 256 | 257 | 258 | 259 | 260 | 261 | 262 | 263 | 264 | 265 | 266 | 267

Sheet: AXISDEF
PROFIL | i | d
P8.2 | 1 | 100
P8.3 | 2 | 101
P8.4 | 3 | 102
P8.5 | 4 | 103
P8.6 | 5 | 104
P8.7 | 6 | 105
P9 | 7 | 106
P9.1 | 8 | 107
P9.2 | 9 | 108
P9.3 | 10 | 109
P9.4 | 11 | 110
P9.5 | 12 | 111
P9.6 | 13 | 112
Q0 | 14 | 113

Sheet: TRAVERSALCHAINAGE
 | a | b | c | d | e | f | g | h | i | j | k | l
P8.2 | 0 | 0.20001 | 1.10004 | 2.42514 | 3.35 | 3.6 | 3.9 | 4.9 | 8.15 | 12.4 | 13.3 | 13.5
P8.3 | 0 | 0.20001 | 1.10004 | 2.42514 | 3.35 | 3.6 | 3.9 | 4.9 | 8.15 | 12.4 | 13.3 | 13.5
P8.4 | 0 | 0.20001 | 1.10004 | 2.425140001 | 3.350000001 | 3.6 | 3.9 | 4.9 | 8.15 | 12.4 | 13.3 | 13.5
P8.5 | 0 | 0.20001 | 1.10004 | 2.42514 | 3.35 | 3.6 | 3.9 | 4.9 | 8.15 | 12.4 | 13.3 | 13.5
P8.6 | 0 | 0.20001 | 1.10004 | 2.42514 | 3.35 | 3.6 | 3.9 | 4.9 | 8.15 | 12.4 | 13.3 | 13.5
P8.7 | 0 | 0.20001 | 1.10004 | 2.42514 | 3.35 | 3.6 | 3.9 | 4.9 | 8.15 | 12.4 | 13.3 | 13.5
P9 | 0 | 0.20001 | 1.10004 | 2.42514 | 3.35 | 3.6 | 3.9 | 4.9 | 8.15 | 12.4 | 13.3 | 13.5
P9.1 | 0 | 0.20001 | 1.10004 | 2.42514 | 3.35 | 3.6 | 3.9 | 4.9 | 8.15 | 12.4 | 13.3 | 13.5
P9.2 | 0 | 0.20001 | 1.10004 | 2.42514 | 3.35 | 3.6 | 3.9 | 4.9 | 8.15 | 12.4 | 13.3 | 13.5
P9.3 | 0 | 0.2001500062 | 1.100010044 | 2.422510101 | 3.34992014 | 3.59992015 | 3.899920161 | 4.900110203 | 8.150110339 | 12.39992052 | 13.29992055 | 13.49992056
P9.4 | 0 | 0.2007919904 | 1.10017104 | 2.421003126 | 3.350281712 | 3.600006362 | 3.900097733 | 4.900218384 | 8.150204159 | 12.40010234 | 13.30010328 | 13.50010459
P9.5 | 0 | 0.2001693855 | 1.099981291 | 2.436284452 | 3.349981288 | 3.600007887 | 3.900001924 | 4.901218986 | 8.151215416 | 12.43240958 | 13.33301174 | 13.53315114
P9.6 | 0 | 0.2003193713 | 1.099754289 | 2.444181554 | 3.350014475 | 3.600033288 | 3.900031697 | 4.90098834 | 8.150983207 | 12.57417065 | 13.47743078 | 13.67818061
Q0 | 0 | 0.2000139885 | 0.9000154513 | 2.22600997 | 3.152265621 | 3.402254373 | 3.70226617 | 4.702389091 | 7.952386148 | 12.57630466 | 13.48260922 | 13.68405822

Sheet: AXISDATUMLEVELS
 | i | d
P8.2 | 265.212 | 266.800
P8.3 | 265.200 | 266.788
P8.4 | 265.187 | 266.775
P8.5 | 265.175 | 266.763
P8.6 | 265.162 | 266.750
P8.7 | 265.150 | 266.738
P9 | 265.149 | 266.753
P9.1 | 265.169 | 266.803
P9.2 | 265.209 | 266.853
P9.3 | 265.271 | 266.903
P9.4 | 265.353 | 266.970
P9.5 | 265.457 | 267.125
P9.6 | 265.581 | 267.283
Q0 | 265.710 | 267.428

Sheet: PROFILELEVELS
PROFIL | Quergefälle | i1 | h3 | h2 | h1 | a1 | a2 | b1 | c1 | f1 | g1 | l1 | l2 | j1 | k1 | j3 | j4 | g3 | g4 | d1 | c3 | e1 | f3 | f2 | g2 | b2 | c2 | j2 | k2
P8.2 | 2.50% | 265.212 | 265.131 | 264.991 | 263.991 | 264.113 | 265.098 | 265.108 | 265.086 | 265.023 | 265.016 | 264.206 | 265.191 | 265.178 | 265.201 | 265.318 | 265.462 | 265.156 | 265.309 | 266.800 | 266.834 | 266.777 | 266.784 | 266.984 | 266.984 | 270.650 | 270.650 | 270.650 | 270.650
P8.3 | 2.50% | 265.200 | 265.118 | 264.978 | 263.978 | 264.101 | 265.086 | 265.096 | 265.073 | 265.011 | 265.003 | 264.193 | 265.178 | 265.166 | 265.188 | 265.306 | 265.450 | 265.143 | 265.296 | 266.788 | 266.821 | 266.765 | 266.771 | 266.971 | 266.971 | 270.650 | 270.650 | 270.650 | 270.650
P8.4 | 2.50% | 265.187 | 265.106 | 264.966 | 263.966 | 264.088 | 265.073 | 265.083 | 265.061 | 264.998 | 264.991 | 264.181 | 265.166 | 265.153 | 265.176 | 265.293 | 265.437 | 265.131 | 265.284 | 266.775 | 266.809 | 266.752 | 266.759 | 266.959 | 266.959 | 270.650 | 270.650 | 270.650 | 270.650
P8.5 | 2.50% | 265.175 | 265.093 | 264.953 | 263.953 | 264.076 | 265.061 | 265.071 | 265.048 | 264.986 | 264.978 | 264.168 | 265.153 | 265.141 | 265.163 | 265.281 | 265.425 | 265.118 | 265.271 | 266.763 | 266.796 | 266.740 | 266.746 | 266.946 | 266.946 | 270.650 | 270.650 | 270.650 | 270.650
P8.6 | 2.50% | 265.162 | 265.081 | 264.941 | 263.941 | 264.063 | 265.048 | 265.058 | 265.036 | 264.973 | 264.966 | 264.156 | 265.141 | 265.128 | 265.151 | 265.268 | 265.412 | 265.106 | 265.259 | 266.750 | 266.784 | 266.727 | 266.734 | 266.934 | 266.934 | 270.650 | 270.650 | 270.650 | 270.650
P8.7 | 2.50% | 265.150 | 265.068 | 264.928 | 263.928 | 264.051 | 265.036 | 265.046 | 265.023 | 264.961 | 264.953 | 264.143 | 265.128 | 265.116 | 265.138 | 265.256 | 265.400 | 265.093 | 265.246 | 266.738 | 266.771 | 266.715 | 266.721 | 266.921 | 266.921 | 270.650 | 270.650 | 270.650 | 270.650
P9 | 2.50% | 265.149 | 265.067 | 264.927 | 263.927 | 264.050 | 265.035 | 265.045 | 265.022 | 264.960 | 264.952 | 264.142 | 265.127 | 265.115 | 265.137 | 265.255 | 265.399 | 265.092 | 265.245 | 266.753 | 266.787 | 266.730 | 266.737 | 266.937 | 266.937 | 270.650 | 270.650 | 270.650 | 270.650
P9.1 | 2.50% | 265.169 | 265.087 | 264.947 | 263.947 | 264.070 | 265.055 | 265.065 | 265.042 | 264.980 | 264.972 | 264.162 | 265.147 | 265.135 | 265.157 | 265.275 | 265.419 | 265.112 | 265.265 | 266.803 | 266.837 | 266.780 | 266.787 | 266.987 | 266.987 | 270.650 | 270.650 | 270.650 | 270.650
P9.2 | 2.50% | 265.209 | 265.128 | 264.988 | 263.988 | 264.110 | 265.095 | 265.105 | 265.083 | 265.020 | 265.013 | 264.203 | 265.188 | 265.175 | 265.198 | 265.315 | 265.459 | 265.153 | 265.306 | 266.853 | 266.887 | 266.830 | 266.837 | 267.037 | 267.037 | 270.650 | 270.650 | 270.650 | 270.650
P9.3 | 2.34% | 265.271 | 265.195 | 265.055 | 264.055 | 264.169 | 265.154 | 265.165 | 265.144 | 265.085 | 265.078 | 264.256 | 265.241 | 265.230 | 265.251 | 265.370 | 265.514 | 265.218 | 265.373 | 266.903 | 266.937 | 266.880 | 266.887 | 267.087 | 267.087 | 270.650 | 270.650 | 270.650 | 270.650
P9.4 | 1.74% | 265.353 | 265.297 | 265.157 | 264.157 | 264.242 | 265.227 | 265.238 | 265.223 | 265.179 | 265.174 | 264.306 | 265.291 | 265.287 | 265.303 | 265.427 | 265.571 | 265.314 | 265.475 | 266.970 | 267.003 | 266.946 | 266.953 | 267.153 | 267.153 | 270.650 | 270.650 | 270.650 | 270.650
P9.5 | 1.14% | 265.457 | 265.420 | 265.280 | 264.280 | 264.335 | 265.320 | 265.333 | 265.323 | 265.294 | 265.291 | 264.378 | 265.363 | 265.365 | 265.376 | 265.505 | 265.649 | 265.431 | 265.598 | 267.125 | 267.158 | 267.102 | 267.108 | 267.308 | 267.308 | 270.650 | 270.650 | 270.650 | 270.650
P9.6 | 0.54% | 265.581 | 265.563 | 265.423 | 264.423 | 264.450 | 265.435 | 265.449 | 265.444 | 265.430 | 265.429 | 264.471 | 265.456 | 265.465 | 265.470 | 265.605 | 265.749 | 265.569 | 265.741 | 267.283 | 267.316 | 267.260 | 267.266 | 267.466 | 267.466 | 270.650 | 270.650 | 270.650 | 270.650
Q0 | 0.00% | 265.710 | 265.710 | 265.570 | 264.570 | 264.570 | 265.555 | 265.570 | 265.570 | 265.570 | 265.570 | 264.570 | 265.555 | 265.570 | 265.570 | 265.710 | 265.854 | 265.710 | 265.888 | 267.428 | 267.461 | 267.405 | 267.411 | 267.611 | 267.611 | 270.650 | 270.650 | 270.650 | 270.650

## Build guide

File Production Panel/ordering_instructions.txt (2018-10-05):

panel size, 161x117mm
PCB thickness, 1.6mm
number of layers, 2
soldermask color, Red
silkscreen color, White
oz copper, 1oz
finish, HASL lead free
stencils, none
pcs per panel, 12

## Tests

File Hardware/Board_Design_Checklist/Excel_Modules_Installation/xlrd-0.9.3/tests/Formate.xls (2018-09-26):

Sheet: Blätt1
Huber | 1907-07-03
Äcker | 2005-02-23
Öcker | 1988-05-03
Morgen | 6:34:00
Mittag | 12:56:00
Abends | 17:47:13
gut | 97.4%
schlecht | 12.4%
viel | 1000.30 €
wenig | 1.20 €

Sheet: ÖÄÜ
-100
 | MERGED CELLS

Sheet: Blätt3
100
200
300
400
500
600
700
800
900
1000
1100
1200

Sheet: Formate
RED | RED
GREEN | GREEN
BLUE | BLUE

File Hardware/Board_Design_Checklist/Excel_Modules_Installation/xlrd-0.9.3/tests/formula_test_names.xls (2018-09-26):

Description | Data
Unary operation | -7
Single param sum | 4
Function call | 6
Function with variable # args | 3
If function | b
Choose function | C
Binary operation → bool | TRUE

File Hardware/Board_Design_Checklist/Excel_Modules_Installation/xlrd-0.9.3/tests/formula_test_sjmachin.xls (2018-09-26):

Description | Data
Non-latin1 text | МОСКВА Москва
formula number | 0.1428571429
formula text | ABCDEF
formula zero-length text
formula boolean | TRUE
formula error | #DIV/0!
formula non-latin1 text | МОСКВА Москва

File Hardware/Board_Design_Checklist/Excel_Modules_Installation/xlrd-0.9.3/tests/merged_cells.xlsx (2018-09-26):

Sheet: Sheet2
Foo

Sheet: Sheet3
Foo | Bar
Baz | Boo

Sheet: Sheet4
Foo
 | Baz
Bar

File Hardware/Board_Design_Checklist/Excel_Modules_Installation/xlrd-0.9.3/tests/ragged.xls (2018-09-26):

a | b | c
d | e
f
g | h | I | j
k |  |  | l

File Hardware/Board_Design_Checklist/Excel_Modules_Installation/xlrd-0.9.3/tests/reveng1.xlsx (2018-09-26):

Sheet: ZZZfirstsheet
description | entered | calculated
empty string
len near 128 | xxxxxxxxxxxxxxxxxxxxxxxxxxxxxxxxxxxxxxxxxxxxxxxxxxxxxxxxxxxxxxxxxxxxxxxxxxxxxxxxxxxxxxxxxxxxxxxxxxxxxxxxxxxxxxxxxxxxxxxxxxxxxxx | xxxxxxxxxxxxxxxxxxxxxxxxxxxxxxxxxxxxxxxxxxxxxxxxxxxxxxxxxxxxxxxxxxxxxxxxxxxxxxxxxxxxxxxxxxxxxxxxxxxxxxxxxxxxxxxxxxxxxxxxxxxxxxx | 127
len near 128 | xxxxxxxxxxxxxxxxxxxxxxxxxxxxxxxxxxxxxxxxxxxxxxxxxxxxxxxxxxxxxxxxxxxxxxxxxxxxxxxxxxxxxxxxxxxxxxxxxxxxxxxxxxxxxxxxxxxxxxxxxxxxxxxx | xxxxxxxxxxxxxxxxxxxxxxxxxxxxxxxxxxxxxxxxxxxxxxxxxxxxxxxxxxxxxxxxxxxxxxxxxxxxxxxxxxxxxxxxxxxxxxxxxxxxxxxxxxxxxxxxxxxxxxxxxxxxxxxx | 128
len near 128 | xxxxxxxxxxxxxxxxxxxxxxxxxxxxxxxxxxxxxxxxxxxxxxxxxxxxxxxxxxxxxxxxxxxxxxxxxxxxxxxxxxxxxxxxxxxxxxxxxxxxxxxxxxxxxxxxxxxxxxxxxxxxxxxxx | xxxxxxxxxxxxxxxxxxxxxxxxxxxxxxxxxxxxxxxxxxxxxxxxxxxxxxxxxxxxxxxxxxxxxxxxxxxxxxxxxxxxxxxxxxxxxxxxxxxxxxxxxxxxxxxxxxxxxxxxxxxxxxxxx | 129
non-ascii | Ð | Ð
zero | 0 | 0
one | 1 | 1
minus 1 | -1 | -1
1.23 | 1.23 | 1.23
1.234 | 1.234 | 1.234
123456 | 123456 | 123456
1.23456789012345 | 1.234568 | 2.234568
one third | 0.333333 | 0.333333
true | TRUE | TRUE
false | FALSE | FALSE
#div/0! | #DIV/0! | #DIV/0!
#na | #N/A | #N/A
#name? | #NAME? | #NAME?
#num! | #NUM! | #NUM!
#value! | #VALUE! | #VALUE!
#ref! | #REF! | #REF!
#null! | #NULL! | #NULL!
no data (formatting) |  |  | more guff
rich text 1 | boldplain | boldplainboldplain
rich text 2 | ArialCourier | ArialCourierArialCourier
no data (no formatting) |  |  | filler
Short Date | 1999-12-31 | 2000-01-01
dd-mmm | 2008-01-18 | 2008-01-19
dd/mm/yy | 2008-01-18 | 2008-01-19
dd/mm/yyyy | 2008-01-18 | 2008-01-19
Long Date | 2008-01-18 | 2008-01-19
Hard newline (Alt-Enter) | Line1 Line2 Line3 | Line1 Line2 Line3
NBSP | foonly frabjous farnarklingliness
2 internal spaces | foo bar | foo bar
1 leading space | foo | foo
2 leading spaces | foo | foo
1 trailing space | foo | foo
2 trailing spaces | foo | foo
Hard newline (Alt-Enter) | Line1 Line2 | Line1 Line2
Hard newline (Alt-Enter) with leading trailing & internal spaces | Li ne1 Li ne2 Li ne3
embedded control chars |  | _x000C__x000D_
embedded CC with u/score |  | _x000C__x000D_P_xQ_x005F_x000F_R_x005F_x000C_S
currency | $1234.56 | AUD 1234.56
time | 2:10:55 | 2:10:55
more underscores | _x005F_x000F__x005F_x000f_ | _x005F_x000F__x005F_x000f_
less/greater/ampersand | 1 < 2 & 4 > 3 | 1 < 2 & 4 > 3
rich text and spaces | x bold y
spaces in font name | this is Times New Roman
empty cells |  |  | guff
datetime | 2009-07-06 02:10 | 2009-07-07 02:10
pseudofloat inf | 123E999 | 123E999
pseudofloat big | 12E99 | 12E99
pseudofloat tiny | 12E-99 | 12E-99
text with custom date format | text, dammit | text, dammit
text with standard date format | text, dammit | text, dammit

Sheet: AAA2ndsheet
2nd sheet
not mrgd | nm | nm | nm | nm
nm | merged cells can be quite a barrel of fun |  |  | nm
nm |  |  |  | nm
nm | nm | nm | nm | nm
Merged all the cells in two rows -- what html appears for the 2nd row?
a8 | b8 | c8 | d8 | e8

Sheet: ControlChars
1 | _x0001_ | _x0001_
2 | _x0002_ | _x0002_
3 | _x0003_ | _x0003_
4 | _x0004_ | _x0004_
5 | _x0005_ | _x0005_
6 | _x0006_ | _x0006_
7 | _x0007_ | _x0007_
8 | _x0008_ | _x0008_
9
10
11 | _x000B_ | _x000B_
12 | _x000C_ | _x000C_
13 |  | _x000D_
14 | _x000E_ | _x000E_
15 | _x000F_ | _x000F_
16 | _x0010_ | _x0010_
17 | _x0011_ | _x0011_
18 | _x0012_ | _x0012_
19 | _x0013_ | _x0013_
20 | _x0014_ | _x0014_
21 | _x0015_ | _x0015_
22 | _x0016_ | _x0016_
23 | _x0017_ | _x0017_
24 | _x0018_ | _x0018_
25 | _x0019_ | _x0019_
26 | _x001A_ | _x001A_
27 | _x001B_ | _x001B_
28 | _x001C_ | _x001C_
29 | _x001D_ | _x001D_
30 | _x001E_ | _x001E_
31 | _x001F_ | _x001F_
32

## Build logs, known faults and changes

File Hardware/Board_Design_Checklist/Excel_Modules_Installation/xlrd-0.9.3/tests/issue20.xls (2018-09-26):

aasa
asasa
asasa
asasa
asasa
 |  | asasa
legenda | as

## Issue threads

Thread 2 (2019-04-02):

Reception unsuccessful

richard-ubi, 2019-04-02:
HI，
When I successfully ran this program, I used a device to send a message to it, sometimes it was sensitive to receive, sometimes it was not sensitive to receive, I would like to ask how to exclude this problem, looking forward to your reply

AndyEngland521, 2019-04-02:
Hmmm, this could be a number of things. What kind of antenna are you using? Do you have a housing? Also, are you sending messages over WiFi or LoRa?

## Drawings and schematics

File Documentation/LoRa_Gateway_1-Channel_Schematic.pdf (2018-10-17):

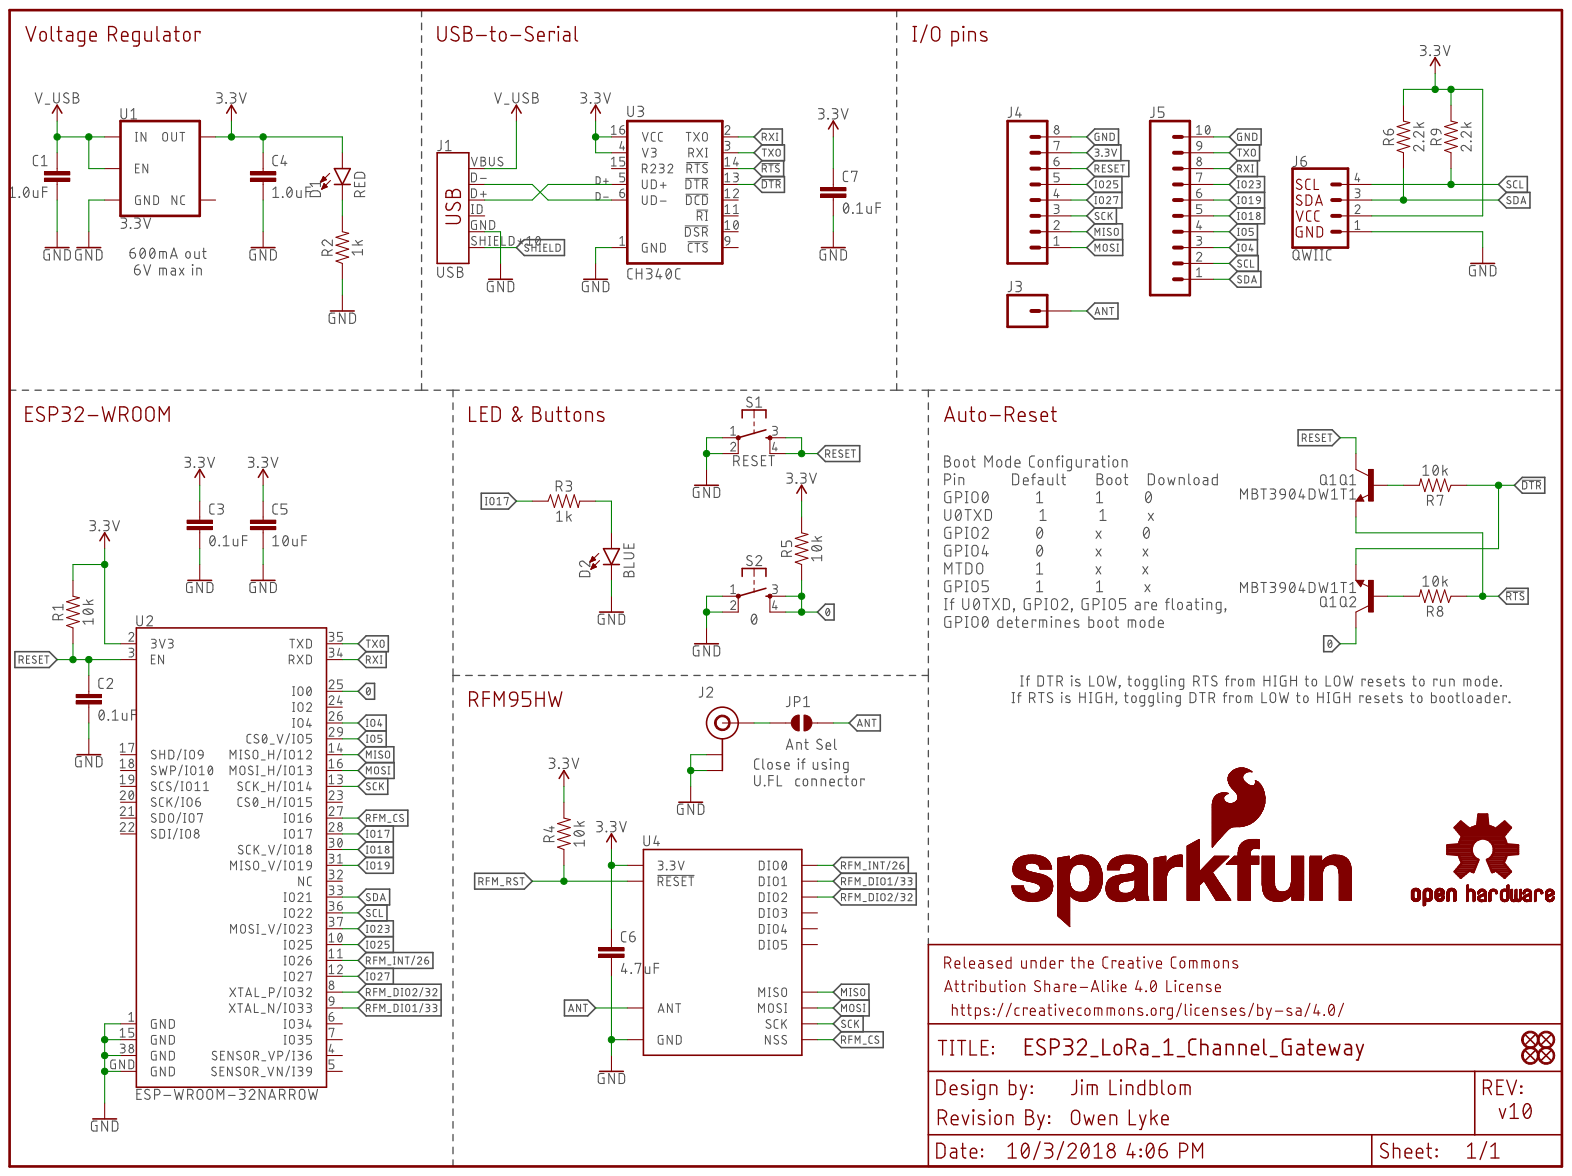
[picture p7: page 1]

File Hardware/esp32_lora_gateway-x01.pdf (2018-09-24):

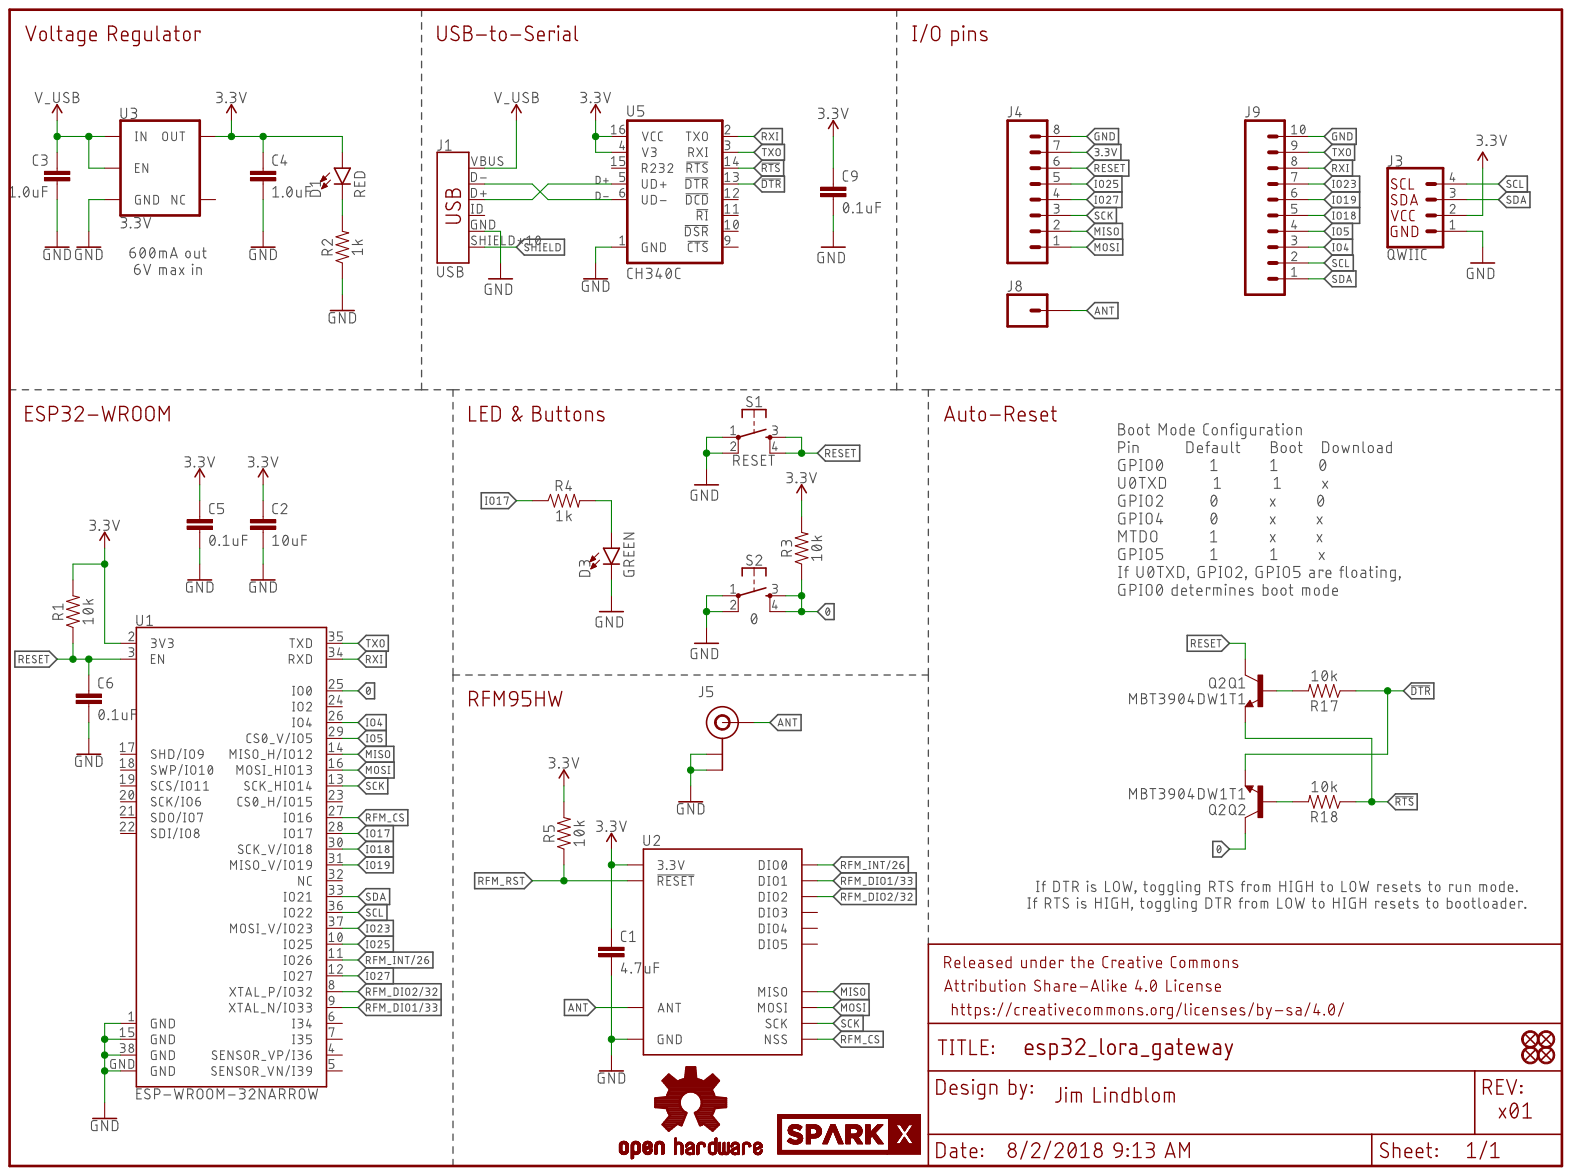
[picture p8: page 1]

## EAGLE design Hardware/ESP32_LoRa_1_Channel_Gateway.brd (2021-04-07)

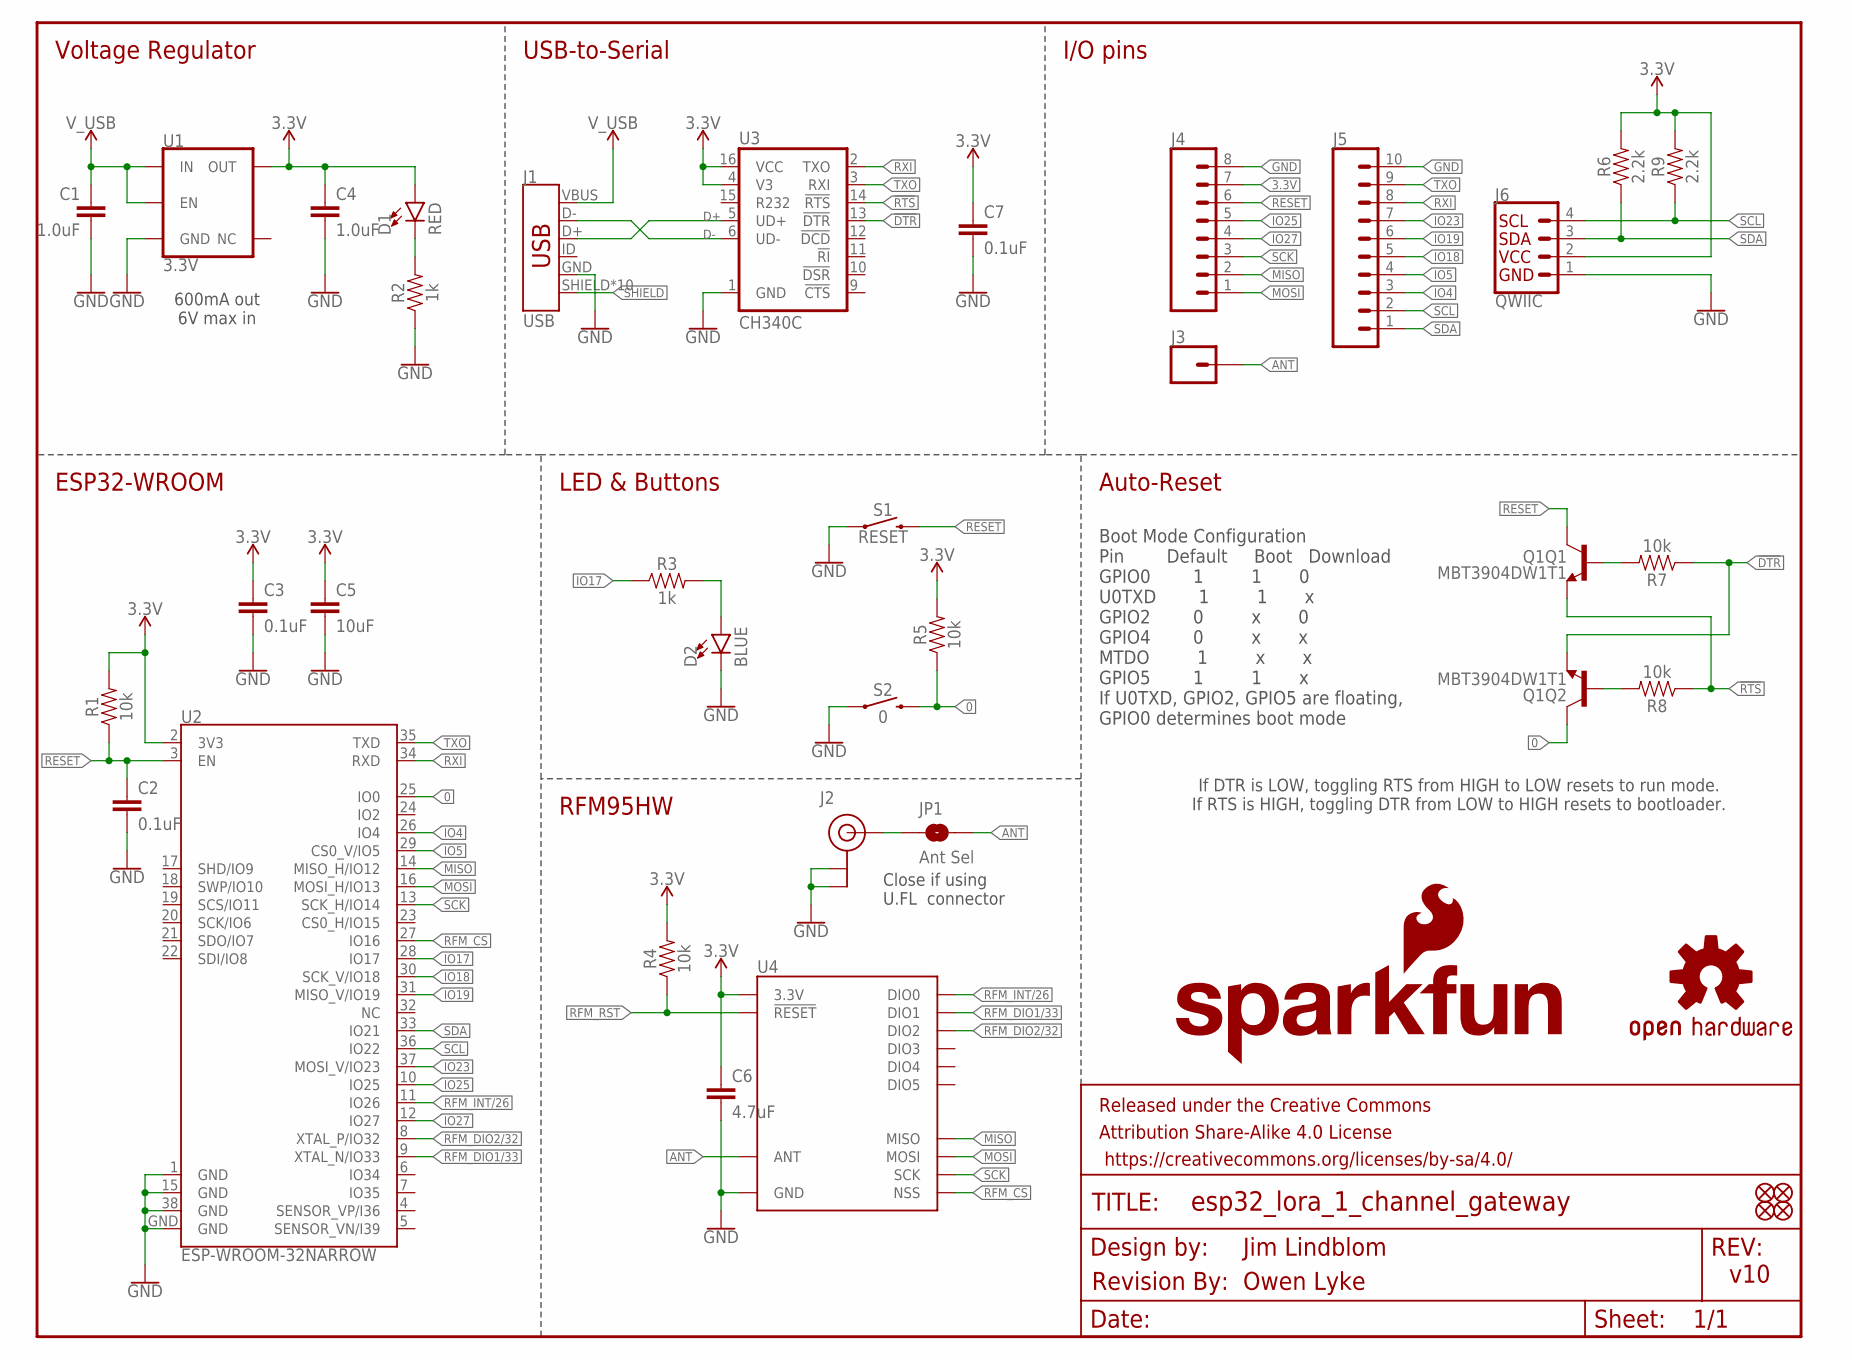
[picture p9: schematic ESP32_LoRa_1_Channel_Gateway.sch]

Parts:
C1, C4: 1.0uF; 0603
C2, C3, C7: 0.1uF; 0603
C5: 10uF; 0603
C6: 4.7uF; 0603
D1: RED; LED-0603
D2: BLUE; LED-0603
FD1, FD2, FD3, FD4: FIDUCIAL1X2; FIDUCIAL-1X2
FRAME1: FRAME-LETTER; CREATIVE_COMMONS
J1: USB; USB-MICROB-PTH-MILL
J2: U.FL
J3: CONN_01PTH_NO_SILK_YES_STOP; 1X01_NO_SILK
J4: CONN_08NO_SILK_FEMALE_PTH; 1X08_NO_SILK
J5: CONN_10NO_SILK_PTH_FEMALE; 1X10_NO_SILK
J6: QWIIC; 1X04_1MM_RA
JP1: Ant Sel; SMT-JUMPER_2_NO_NO-SILK
LOGO1: REVISION
LOGO2: SFE_LOGO_NAME_FLAME.1_INCH; SFE_LOGO_NAME_FLAME_.1
LOGO3: OSHW-LOGOS; OSHW-LOGO-S
Q1: MBT3904DW1T1; SC70-6
R1, R4, R5, R7, R8: 10k; 0603
R2, R3: 1k; 0603
R6, R9: 2.2k; 0603
S1: RESET; TACTILE_SWITCH_SMD_4.6X2.8MM
S2: 0; TACTILE_SWITCH_SMD_4.6X2.8MM
U1: 3.3V; SOT23-5
U2: ESP-WROOM-32NARROW; ESP-WROOM-32-NARROW
U3: CH340C; SO016
U4: RFM95W; RFM95/96/97/98W

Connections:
0: Q1.6 (C), R5.1, S2.3 (2), S2.4 (2), U2.25 (IO0)
3.3V: C3.1, C4.1, C5.1, C6.1, C7.1, D1.A, J4.7, J6.2, R1.2, R4.2, R5.2, R6.2, R9.2, U1.5 (OUT), U2.2 (3V3), U3.4 (V3), U3.16 (VCC), U4.3.3V
!DTR: Q1.1 (E), R7.1, U3.13 (!DTR)
!RTS: Q1.4 (E), R8.1, U3.14 (!RTS)
ANT: J3.1, JP1.2, U4.ANT
D+: J1.D+, U3.5 (UD+)
D-: J1.D-, U3.6 (UD-)
GND: C1.2, C2.2, C3.2, C4.2, C5.2, C6.2, C7.2, D2.C, J1.GND, J2.1 (GND), J2.2 (GND), J4.8, J5.10, J6.1, R2.1, S1.1, S1.2 (1), S2.1, S2.2 (1), U1.2 (GND), U2.1 (GND), U2.15 (GND), U2.38 (GND), U2.GND, U3.1 (GND), U4.GND@1 (GND), U4.GND@2 (GND), U4.GND@3 (GND)
IO4: J5.3, U2.26 (IO4)
IO5: J5.4, U2.29 (CS0_V/IO5)
IO17: R3.1, U2.28 (IO17)
IO18: J5.5, U2.30 (SCK_V/IO18)
IO19: J5.6, U2.31 (MISO_V/IO19)
IO23: J5.7, U2.37 (MOSI_V/IO23)
IO25: J4.5, U2.10 (IO25)
IO27: J4.4, U2.12 (IO27)
MISO: J4.2, U2.14 (MISO_H/IO12), U4.MISO
MOSI: J4.1, U2.16 (MOSI_H/IO13), U4.MOSI
unnamed: D1.C, R2.2
unnamed: D2.A, R3.2
unnamed: J2.FEED (SIGNAL), JP1.1
unnamed: Q1.5 (B), R7.2
unnamed: Q1.2 (B), R8.2
RESET: C2.1, J4.6, Q1.3 (C), R1.1, S1.3 (2), S1.4 (2), U2.3 (EN)
RFM_CS: U2.27 (IO16), U4.NSS
RFM_DIO1/33: U2.9 (XTAL_N/IO33), U4.DIO1
RFM_DIO2/32: U2.8 (XTAL_P/IO32), U4.DIO2
RFM_INT/26: U2.11 (IO26), U4.DIO0
RFM_RST: R4.1, U4.!RESET
RXI: J5.8, U2.34 (RXD), U3.2 (TXO)
SCK: J4.3, U2.13 (SCK_H/IO14), U4.SCK
SCL: J5.2, J6.4, R9.1, U2.36 (IO22)
SDA: J5.1, J6.3, R6.1, U2.33 (IO21)
SHIELD: J1.SHIELD, J1.SHIELD2 (SHIELD), J1.SHIELD3 (SHIELD), J1.SHIELD4 (SHIELD), J1.SHIELD5 (SHIELD), J1.SHIELD6 (SHIELD), J1.SHIELD7 (SHIELD), J1.SHIELD8 (SHIELD), J1.SHIELD9 (SHIELD), J1.SHIELD10 (SHIELD)
TXO: J5.9, U2.35 (TXD), U3.3 (RXI)
V_USB: C1.1, J1.VBUS, U1.1 (IN), U1.3 (EN)

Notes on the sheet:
Boot Mode Configuration Pin Default Boot Download GPIO0 1 1 0 U0TXD 1 1 x GPIO2 0 x 0 GPIO4 0 x x MTDO 1 x x GPIO5 1 1 x If U0TXD, GPIO2, GPIO5 are floating, GPIO0 determines boot mode
If DTR is LOW, toggling RTS from HIGH to LOW resets to run mode. If RTS is HIGH, toggling DTR from LOW to HIGH resets to bootloader.
600mA out 6V max in
Voltage Regulator
USB-to-Serial
I/O pins
ESP32-WROOM
LED & Buttons
Auto-Reset
RFM95HW
Jim Lindblom
v10
Owen Lyke
Close if using U.FL connector

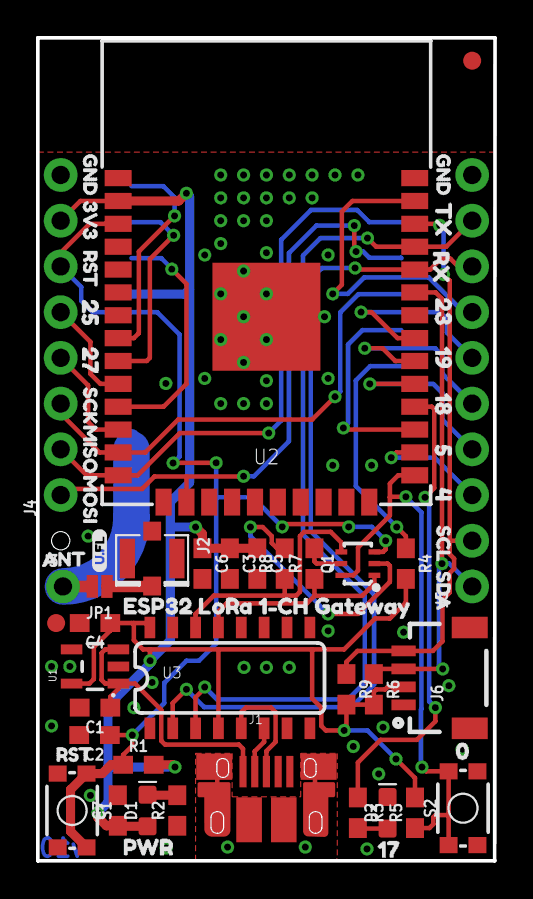
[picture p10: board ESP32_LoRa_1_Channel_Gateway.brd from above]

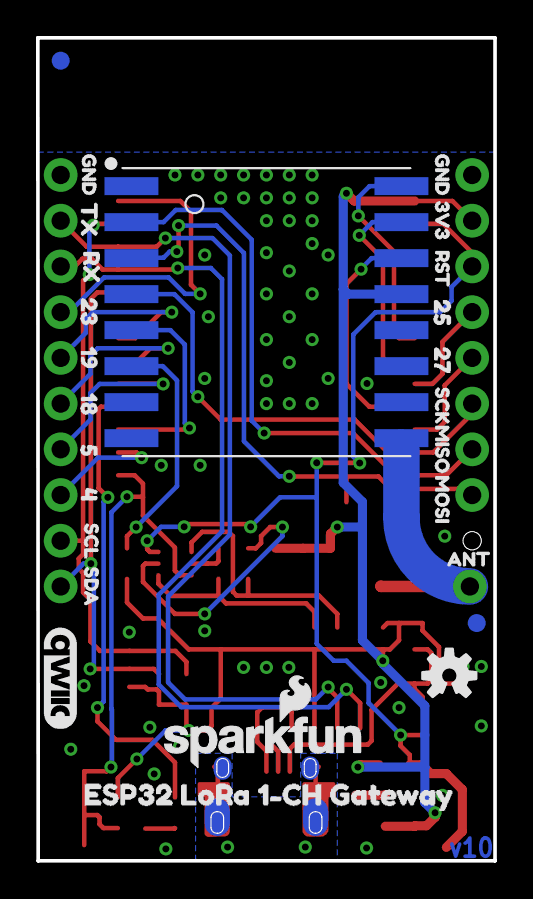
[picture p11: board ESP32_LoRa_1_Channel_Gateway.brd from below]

Board: 2 copper layers, 25.4 x 45.7 mm, 86 parts (26 on the bottom side), 36 nets.

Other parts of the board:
U$1, U$10, U$26, U$37: GND0
U$2, U$38: 3V31
U$3, U$20, U$39: RST2
U$4, U$40: 2517
U$5, U$41: 279
U$6, U$42: SCK3
U$7, U$43: MISO4
U$8, U$44: MOSI5
U$9, U$36: ANT6
U$11, U$27: TX16
U$12, U$28: RX15
U$13, U$29: 2314
U$14, U$30: 1912
U$15, U$31: 1811
U$16, U$32: 513
U$17, U$33: 410
U$18, U$34: SCL8
U$19, U$35: SDA7
U$21: 020
U$22: PWR19
U$23: 1722
U$24: U#FL0
U$25: ESP32_LORA_1#CH_GATEWAY21
U$45: ESP32_LORA_1#CH_GATEWAY23
U$46: QWIIC_COPYRIGHT_SMALL

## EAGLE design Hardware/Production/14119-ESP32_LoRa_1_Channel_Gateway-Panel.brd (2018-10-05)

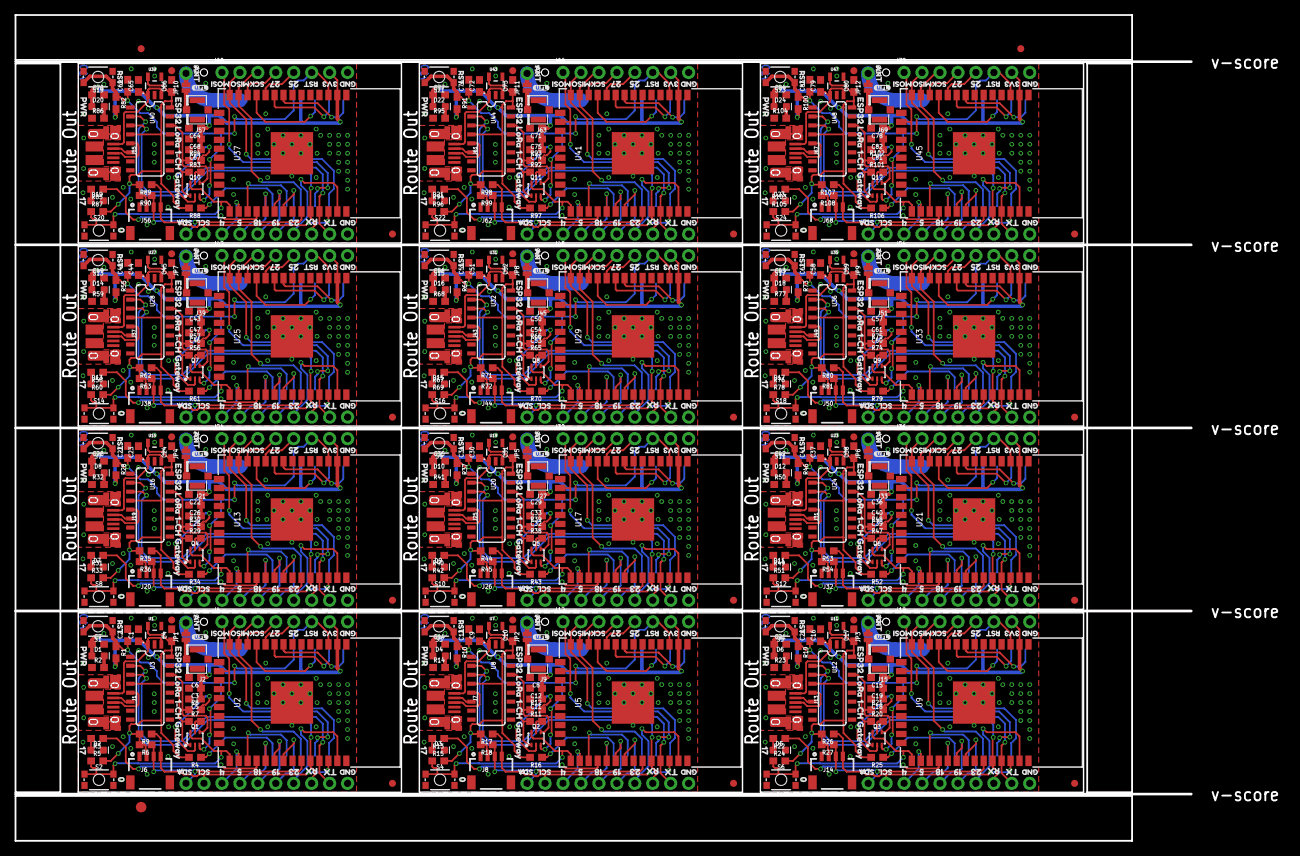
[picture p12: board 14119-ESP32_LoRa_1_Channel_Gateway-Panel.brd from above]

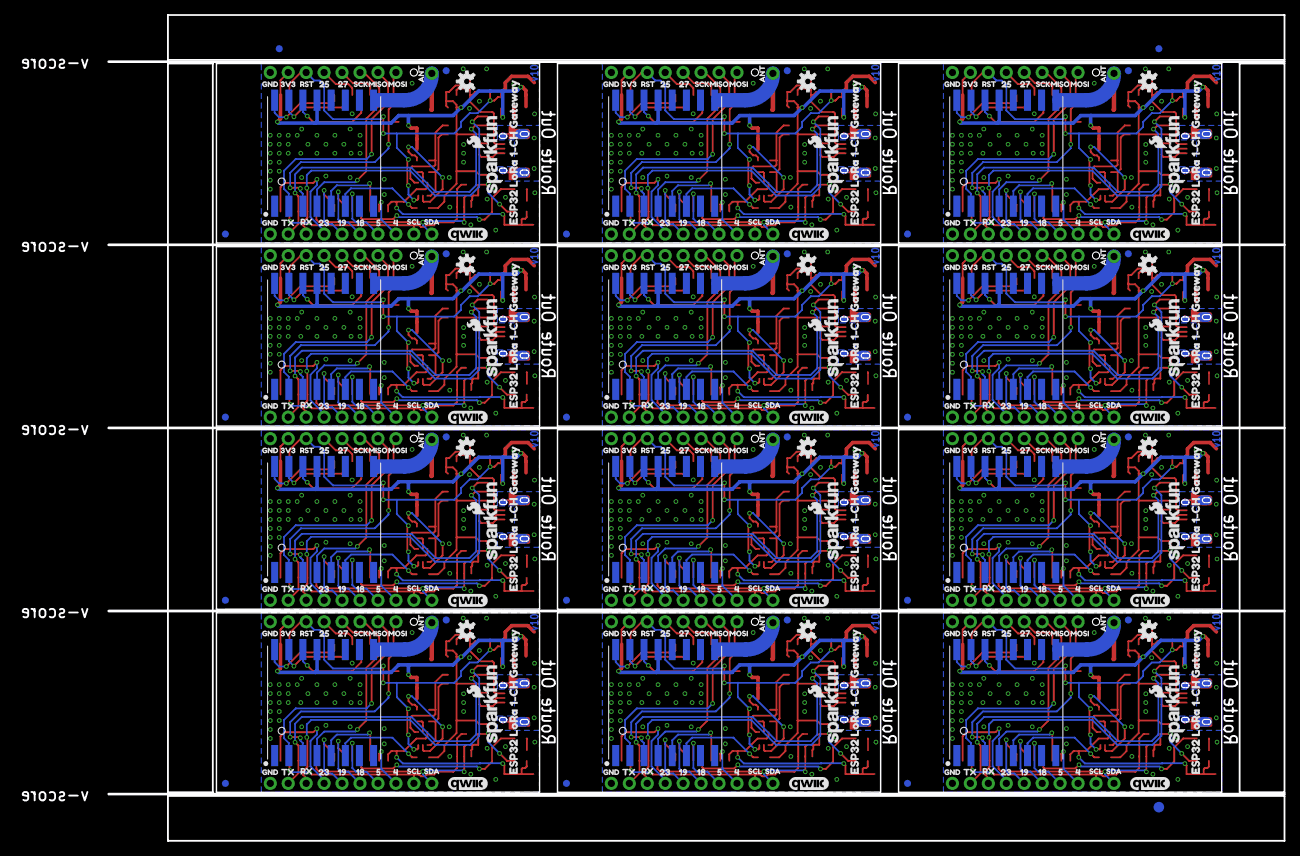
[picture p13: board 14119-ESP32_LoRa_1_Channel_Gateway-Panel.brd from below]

Board: 2 copper layers, 166.4 x 116.8 mm, 1014 parts (315 on the bottom side), 432 nets.

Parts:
C1, C4, C9, C10, C16, C17, C23, C24, C30, C31, C37, C38, C44, C45, C51, C52, C58, C59, C65, C66, C72, C73, C79, C80: 1.0uF; 0603
C2, C3, C7, C12, C13, C14, C19, C20, C21, C26, C27, C28, C33, C34, C35, C40, C41, C42, C47, C48, C49, C54, C55, C56, C61, C62, C63, C68, C69, C70, C75, C76, C77, C82, C83, C84: 0.1uF; 0603
C5, C11, C18, C25, C32, C39, C46, C53, C60, C67, C74, C81: 10uF; 0603
C6, C8, C15, C22, C29, C36, C43, C50, C57, C64, C71, C78: 4.7uF; 0603
D1, D4, D6, D8, D10, D12, D14, D16, D18, D20, D22, D24: RED; LED-0603
D2, D3, D5, D7, D9, D11, D13, D15, D17, D19, D21, D23: BLUE; LED-0603
E$1, E$2, E$3, E$4: FIDUCIAL-1X2
E$5, E$6: FIDUCIAL-1.5X3
FD1, FD2, FD3, FD4, FD5, FD6, FD7, FD8, FD9, FD10, FD11, FD12, FD13, FD14, FD15, FD16, FD17, FD18, FD19, FD20, FD21, FD22, FD23, FD24, FD25, FD26, FD27, FD28, FD29, FD30, FD31, FD32, FD33, FD34, FD35, FD36, FD37, FD38, FD39, FD40, FD41, FD42, FD43, FD44, FD45, FD46, FD47, FD48: FIDUCIAL1X2; FIDUCIAL-1X2
J1, J7, J13, J19, J25, J31, J37, J43, J49, J55, J61, J67: USB; USB-MICROB-PTH-MILL
J2, J9, J15, J21, J27, J33, J39, J45, J51, J57, J63, J69: U.FL
J3, J10, J16, J22, J28, J34, J40, J46, J52, J58, J64, J70: 1X01_NO_SILK
J4, J12, J18, J24, J30, J36, J42, J48, J54, J60, J66, J72: 1X08_NO_SILK
J5, J11, J17, J23, J29, J35, J41, J47, J53, J59, J65, J71: 1X10_NO_SILK
J6, J8, J14, J20, J26, J32, J38, J44, J50, J56, J62, J68: QWIIC; 1X04_1MM_RA
JP1, JP2, JP3, JP4, JP5, JP6, JP7, JP8, JP9, JP10, JP11, JP12: Ant Sel; SMT-JUMPER_2_NO_NO-SILK
LOGO1, LOGO3, LOGO5, LOGO7, LOGO9, LOGO11, LOGO13, LOGO15, LOGO17, LOGO19, LOGO21, LOGO23: OSHW-LOGOS; OSHW-LOGO-S
LOGO2, LOGO4, LOGO6, LOGO8, LOGO10, LOGO12, LOGO14, LOGO16, LOGO18, LOGO20, LOGO22, LOGO24: SFE_LOGO_NAME_FLAME.1_INCH; SFE_LOGO_NAME_FLAME_.1
Q1, Q2, Q3, Q4, Q5, Q6, Q7, Q8, Q9, Q10, Q11, Q12: MBT3904DW1T1; SC70-6
R1, R4, R5, R7, R8, R10, R11, R12, R15, R16, R19, R20, R21, R24, R25, R28, R29, R30, R33, R34, R37, R38, R39, R42, R43, R46, R47, R48, R51, R52, R55, R56, R57, R60, R61, R64, R65, R66, R69, R70, R73, R74, R75, R78, R79, R82, R83, R84, R87, R88, R91, R92, R93, R96, R97, R100, R101, R102, R105, R106: 10k; 0603
R2, R3, R13, R14, R22, R23, R31, R32, R40, R41, R49, R50, R58, R59, R67, R68, R76, R77, R85, R86, R94, R95, R103, R104: 1k; 0603
R6, R9, R17, R18, R26, R27, R35, R36, R44, R45, R53, R54, R62, R63, R71, R72, R80, R81, R89, R90, R98, R99, R107, R108: 2.2k; 0603
S1, S3, S5, S7, S9, S11, S13, S15, S17, S19, S21, S23: RESET; TACTILE_SWITCH_SMD_4.6X2.8MM
S2, S4, S6, S8, S10, S12, S14, S16, S18, S20, S22, S24: 0; TACTILE_SWITCH_SMD_4.6X2.8MM
U1, U7, U11, U15, U19, U23, U27, U31, U35, U39, U43, U47: 3.3V; SOT23-5
U2, U5, U9, U13, U17, U21, U25, U29, U33, U37, U41, U45: ESP-WROOM-32NARROW; ESP-WROOM-32-NARROW
U3, U8, U12, U16, U20, U24, U28, U32, U36, U40, U44, U48: CH340C; SO016
U4, U6, U10, U14, U18, U22, U26, U30, U34, U38, U42, U46: RFM95W; RFM95/96/97/98W
U$1, U$10, U$26, U$37, U$48, U$56, U$71, U$82, U$94, U$102, U$117, U$128, U$140, U$148, U$163, U$174, U$186, U$194, U$209, U$220, U$232, U$240, U$255, U$266, U$278, U$286, U$301, U$312, U$324, U$332, U$347, U$358, U$370, U$378, U$393, U$404, U$416, U$424, U$439, U$450, U$462, U$470, U$485, U$496, U$508, U$516, U$531, U$542: GND0
U$2, U$38, U$49, U$83, U$95, U$129, U$141, U$175, U$187, U$221, U$233, U$267, U$279, U$313, U$325, U$359, U$371, U$405, U$417, U$451, U$463, U$497, U$509, U$543: 3V31
U$3, U$20, U$39, U$50, U$66, U$84, U$96, U$112, U$130, U$142, U$158, U$176, U$188, U$204, U$222, U$234, U$250, U$268, U$280, U$296, U$314, U$326, U$342, U$360, U$372, U$388, U$406, U$418, U$434, U$452, U$464, U$480, U$498, U$510, U$526, U$544: RST2
U$4, U$40, U$51, U$85, U$97, U$131, U$143, U$177, U$189, U$223, U$235, U$269, U$281, U$315, U$327, U$361, U$373, U$407, U$419, U$453, U$465, U$499, U$511, U$545: 2517
U$5, U$41, U$52, U$86, U$98, U$132, U$144, U$178, U$190, U$224, U$236, U$270, U$282, U$316, U$328, U$362, U$374, U$408, U$420, U$454, U$466, U$500, U$512, U$546: 279
U$6, U$42, U$53, U$87, U$99, U$133, U$145, U$179, U$191, U$225, U$237, U$271, U$283, U$317, U$329, U$363, U$375, U$409, U$421, U$455, U$467, U$501, U$513, U$547: SCK3
U$7, U$43, U$54, U$88, U$100, U$134, U$146, U$180, U$192, U$226, U$238, U$272, U$284, U$318, U$330, U$364, U$376, U$410, U$422, U$456, U$468, U$502, U$514, U$548: MISO4
U$8, U$44, U$55, U$89, U$101, U$135, U$147, U$181, U$193, U$227, U$239, U$273, U$285, U$319, U$331, U$365, U$377, U$411, U$423, U$457, U$469, U$503, U$515, U$549: MOSI5
U$9, U$36, U$47, U$81, U$93, U$127, U$139, U$173, U$185, U$219, U$231, U$265, U$277, U$311, U$323, U$357, U$369, U$403, U$415, U$449, U$461, U$495, U$507, U$541: ANT6
U$11, U$27, U$57, U$72, U$103, U$118, U$149, U$164, U$195, U$210, U$241, U$256, U$287, U$302, U$333, U$348, U$379, U$394, U$425, U$440, U$471, U$486, U$517, U$532: TX16
U$12, U$28, U$58, U$73, U$104, U$119, U$150, U$165, U$196, U$211, U$242, U$257, U$288, U$303, U$334, U$349, U$380, U$395, U$426, U$441, U$472, U$487, U$518, U$533: RX15
U$13, U$29, U$59, U$74, U$105, U$120, U$151, U$166, U$197, U$212, U$243, U$258, U$289, U$304, U$335, U$350, U$381, U$396, U$427, U$442, U$473, U$488, U$519, U$534: 2314
U$14, U$30, U$60, U$75, U$106, U$121, U$152, U$167, U$198, U$213, U$244, U$259, U$290, U$305, U$336, U$351, U$382, U$397, U$428, U$443, U$474, U$489, U$520, U$535: 1912
U$15, U$31, U$61, U$76, U$107, U$122, U$153, U$168, U$199, U$214, U$245, U$260, U$291, U$306, U$337, U$352, U$383, U$398, U$429, U$444, U$475, U$490, U$521, U$536: 1811
U$16, U$32, U$62, U$77, U$108, U$123, U$154, U$169, U$200, U$215, U$246, U$261, U$292, U$307, U$338, U$353, U$384, U$399, U$430, U$445, U$476, U$491, U$522, U$537: 513
U$17, U$33, U$63, U$78, U$109, U$124, U$155, U$170, U$201, U$216, U$247, U$262, U$293, U$308, U$339, U$354, U$385, U$400, U$431, U$446, U$477, U$492, U$523, U$538: 410
U$18, U$34, U$64, U$79, U$110, U$125, U$156, U$171, U$202, U$217, U$248, U$263, U$294, U$309, U$340, U$355, U$386, U$401, U$432, U$447, U$478, U$493, U$524, U$539: SCL8
U$19, U$35, U$65, U$80, U$111, U$126, U$157, U$172, U$203, U$218, U$249, U$264, U$295, U$310, U$341, U$356, U$387, U$402, U$433, U$448, U$479, U$494, U$525, U$540: SDA7
U$21, U$67, U$113, U$159, U$205, U$251, U$297, U$343, U$389, U$435, U$481, U$527: 020
U$22, U$68, U$114, U$160, U$206, U$252, U$298, U$344, U$390, U$436, U$482, U$528: PWR19
U$23, U$69, U$115, U$161, U$207, U$253, U$299, U$345, U$391, U$437, U$483, U$529: 1722
U$24, U$92, U$138, U$184, U$230, U$276, U$322, U$368, U$414, U$460, U$506, U$552: U#FL0
U$25, U$70, U$116, U$162, U$208, U$254, U$300, U$346, U$392, U$438, U$484, U$530: ESP32_LORA_1#CH_GATEWAY21
U$45, U$90, U$136, U$182, U$228, U$274, U$320, U$366, U$412, U$458, U$504, U$550: ESP32_LORA_1#CH_GATEWAY23
U$46, U$91, U$137, U$183, U$229, U$275, U$321, U$367, U$413, U$459, U$505, U$551: QWIIC_COPYRIGHT_SMALL

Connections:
0: Q1.6, R5.1, S2.3, S2.4, U2.25
1: Q2.6, R15.1, S4.3, S4.4, U5.25
2: Q3.6, R24.1, S6.3, S6.4, U9.25
3: Q4.6, R33.1, S8.3, S8.4, U13.25
3.3V: C3.1, C4.1, C5.1, C6.1, C7.1, D1.A, J4.7, J6.2, R1.2, R4.2, R5.2, R6.2, R9.2, U1.5, U2.2, U3.4, U3.16, U4.3.3V
3.3V1: C8.1, C10.1, C11.1, C12.1, C14.1, D4.A, J8.2, J12.7, R10.2, R15.2, R16.2, R17.2, R18.2, U5.2, U6.3.3V, U7.5, U8.4, U8.16
3.3V2: C15.1, C17.1, C18.1, C19.1, C21.1, D6.A, J14.2, J18.7, R19.2, R24.2, R25.2, R26.2, R27.2, U9.2, U10.3.3V, U11.5, U12.4, U12.16
3.3V3: C22.1, C24.1, C25.1, C26.1, C28.1, D8.A, J20.2, J24.7, R28.2, R33.2, R34.2, R35.2, R36.2, U13.2, U14.3.3V, U15.5, U16.4, U16.16
3.3V4: C29.1, C31.1, C32.1, C33.1, C35.1, D10.A, J26.2, J30.7, R37.2, R42.2, R43.2, R44.2, R45.2, U17.2, U18.3.3V, U19.5, U20.4, U20.16
3.3V5: C36.1, C38.1, C39.1, C40.1, C42.1, D12.A, J32.2, J36.7, R46.2, R51.2, R52.2, R53.2, R54.2, U21.2, U22.3.3V, U23.5, U24.4, U24.16
3.3V6: C43.1, C45.1, C46.1, C47.1, C49.1, D14.A, J38.2, J42.7, R55.2, R60.2, R61.2, R62.2, R63.2, U25.2, U26.3.3V, U27.5, U28.4, U28.16
3.3V7: C50.1, C52.1, C53.1, C54.1, C56.1, D16.A, J44.2, J48.7, R64.2, R69.2, R70.2, R71.2, R72.2, U29.2, U30.3.3V, U31.5, U32.4, U32.16
3.3V8: C57.1, C59.1, C60.1, C61.1, C63.1, D18.A, J50.2, J54.7, R73.2, R78.2, R79.2, R80.2, R81.2, U33.2, U34.3.3V, U35.5, U36.4, U36.16
3.3V9: C64.1, C66.1, C67.1, C68.1, C70.1, D20.A, J56.2, J60.7, R82.2, R87.2, R88.2, R89.2, R90.2, U37.2, U38.3.3V, U39.5, U40.4, U40.16
3.3V10: C71.1, C73.1, C74.1, C75.1, C77.1, D22.A, J62.2, J66.7, R91.2, R96.2, R97.2, R98.2, R99.2, U41.2, U42.3.3V, U43.5, U44.4, U44.16
3.3V11: C78.1, C80.1, C81.1, C82.1, C84.1, D24.A, J68.2, J72.7, R100.2, R105.2, R106.2, R107.2, R108.2, U45.2, U46.3.3V, U47.5, U48.4, U48.16
4: Q5.6, R42.1, S10.3, S10.4, U17.25
5: Q6.6, R51.1, S12.3, S12.4, U21.25
6: Q7.6, R60.1, S14.3, S14.4, U25.25
7: Q8.6, R69.1, S16.3, S16.4, U29.25
8: Q9.6, R78.1, S18.3, S18.4, U33.25
9: Q10.6, R87.1, S20.3, S20.4, U37.25
10: Q11.6, R96.1, S22.3, S22.4, U41.25
11: Q12.6, R105.1, S24.3, S24.4, U45.25
!DTR: Q1.1, R7.1, U3.13
!DTR1: Q2.1, R11.1, U8.13
!DTR2: Q3.1, R20.1, U12.13
!DTR3: Q4.1, R29.1, U16.13
!DTR4: Q5.1, R38.1, U20.13
!DTR5: Q6.1, R47.1, U24.13
!DTR6: Q7.1, R56.1, U28.13
!DTR7: Q8.1, R65.1, U32.13
!DTR8: Q9.1, R74.1, U36.13
!DTR9: Q10.1, R83.1, U40.13
!DTR10: Q11.1, R92.1, U44.13
!DTR11: Q12.1, R101.1, U48.13
!RTS: Q1.4, R8.1, U3.14
!RTS1: Q2.4, R12.1, U8.14
!RTS2: Q3.4, R21.1, U12.14
!RTS3: Q4.4, R30.1, U16.14
!RTS4: Q5.4, R39.1, U20.14
!RTS5: Q6.4, R48.1, U24.14
!RTS6: Q7.4, R57.1, U28.14
!RTS7: Q8.4, R66.1, U32.14
!RTS8: Q9.4, R75.1, U36.14
!RTS9: Q10.4, R84.1, U40.14
!RTS10: Q11.4, R93.1, U44.14
!RTS11: Q12.4, R102.1, U48.14
ANT: J3.1, JP1.2, U4.ANT
ANT1: J10.1, JP2.2, U6.ANT
ANT2: J16.1, JP3.2, U10.ANT
ANT3: J22.1, JP4.2, U14.ANT
ANT4: J28.1, JP5.2, U18.ANT
ANT5: J34.1, JP6.2, U22.ANT
ANT6: J40.1, JP7.2, U26.ANT
ANT7: J46.1, JP8.2, U30.ANT
ANT8: J52.1, JP9.2, U34.ANT
ANT9: J58.1, JP10.2, U38.ANT
ANT10: J64.1, JP11.2, U42.ANT
ANT11: J70.1, JP12.2, U46.ANT
D+: J1.D+, U3.5
D+1: J7.D+, U8.5
D+2: J13.D+, U12.5
D+3: J19.D+, U16.5
D+4: J25.D+, U20.5
D+5: J31.D+, U24.5
D+6: J37.D+, U28.5
D+7: J43.D+, U32.5
D+8: J49.D+, U36.5
D+9: J55.D+, U40.5
D+10: J61.D+, U44.5
D+11: J67.D+, U48.5
D-: J1.D-, U3.6
D-1: J7.D-, U8.6
D-2: J13.D-, U12.6
D-3: J19.D-, U16.6
D-4: J25.D-, U20.6
D-5: J31.D-, U24.6
D-6: J37.D-, U28.6
D-7: J43.D-, U32.6
D-8: J49.D-, U36.6
D-9: J55.D-, U40.6
D-10: J61.D-, U44.6
D-11: J67.D-, U48.6
GND: C1.2, C2.2, C3.2, C4.2, C5.2, C6.2, C7.2, D2.C, J1.GND, J2.1, J2.2, J4.8, J5.10, J6.1, R2.1, S1.1, S1.2, S2.1, S2.2, U1.2, U2.1, U2.15, U2.38, U2.GND, U3.1, U4.GND@1, U4.GND@2, U4.GND@3
GND1: C8.2, C9.2, C10.2, C11.2, C12.2, C13.2, C14.2, D3.C, J7.GND, J8.1, J9.1, J9.2, J11.10, J12.8, R14.1, S3.1, S3.2, S4.1, S4.2, U5.1, U5.15, U5.38, U5.GND, U6.GND@1, U6.GND@2, U6.GND@3, U7.2, U8.1
GND2: C15.2, C16.2, C17.2, C18.2, C19.2, C20.2, C21.2, D5.C, J13.GND, J14.1, J15.1, J15.2, J17.10, J18.8, R23.1, S5.1, S5.2, S6.1, S6.2, U9.1, U9.15, U9.38, U9.GND, U10.GND@1, U10.GND@2, U10.GND@3, U11.2, U12.1
GND3: C22.2, C23.2, C24.2, C25.2, C26.2, C27.2, C28.2, D7.C, J19.GND, J20.1, J21.1, J21.2, J23.10, J24.8, R32.1, S7.1, S7.2, S8.1, S8.2, U13.1, U13.15, U13.38, U13.GND, U14.GND@1, U14.GND@2, U14.GND@3, U15.2, U16.1
GND4: C29.2, C30.2, C31.2, C32.2, C33.2, C34.2, C35.2, D9.C, J25.GND, J26.1, J27.1, J27.2, J29.10, J30.8, R41.1, S9.1, S9.2, S10.1, S10.2, U17.1, U17.15, U17.38, U17.GND, U18.GND@1, U18.GND@2, U18.GND@3, U19.2, U20.1
GND5: C36.2, C37.2, C38.2, C39.2, C40.2, C41.2, C42.2, D11.C, J31.GND, J32.1, J33.1, J33.2, J35.10, J36.8, R50.1, S11.1, S11.2, S12.1, S12.2, U21.1, U21.15, U21.38, U21.GND, U22.GND@1, U22.GND@2, U22.GND@3, U23.2, U24.1
GND6: C43.2, C44.2, C45.2, C46.2, C47.2, C48.2, C49.2, D13.C, J37.GND, J38.1, J39.1, J39.2, J41.10, J42.8, R59.1, S13.1, S13.2, S14.1, S14.2, U25.1, U25.15, U25.38, U25.GND, U26.GND@1, U26.GND@2, U26.GND@3, U27.2, U28.1
GND7: C50.2, C51.2, C52.2, C53.2, C54.2, C55.2, C56.2, D15.C, J43.GND, J44.1, J45.1, J45.2, J47.10, J48.8, R68.1, S15.1, S15.2, S16.1, S16.2, U29.1, U29.15, U29.38, U29.GND, U30.GND@1, U30.GND@2, U30.GND@3, U31.2, U32.1
GND8: C57.2, C58.2, C59.2, C60.2, C61.2, C62.2, C63.2, D17.C, J49.GND, J50.1, J51.1, J51.2, J53.10, J54.8, R77.1, S17.1, S17.2, S18.1, S18.2, U33.1, U33.15, U33.38, U33.GND, U34.GND@1, U34.GND@2, U34.GND@3, U35.2, U36.1
GND9: C64.2, C65.2, C66.2, C67.2, C68.2, C69.2, C70.2, D19.C, J55.GND, J56.1, J57.1, J57.2, J59.10, J60.8, R86.1, S19.1, S19.2, S20.1, S20.2, U37.1, U37.15, U37.38, U37.GND, U38.GND@1, U38.GND@2, U38.GND@3, U39.2, U40.1
GND10: C71.2, C72.2, C73.2, C74.2, C75.2, C76.2, C77.2, D21.C, J61.GND, J62.1, J63.1, J63.2, J65.10, J66.8, R95.1, S21.1, S21.2, S22.1, S22.2, U41.1, U41.15, U41.38, U41.GND, U42.GND@1, U42.GND@2, U42.GND@3, U43.2, U44.1
GND11: C78.2, C79.2, C80.2, C81.2, C82.2, C83.2, C84.2, D23.C, J67.GND, J68.1, J69.1, J69.2, J71.10, J72.8, R104.1, S23.1, S23.2, S24.1, S24.2, U45.1, U45.15, U45.38, U45.GND, U46.GND@1, U46.GND@2, U46.GND@3, U47.2, U48.1
IO1: J12.5, U5.10
IO2: J12.4, U5.12
IO3: J11.6, U5.31
IO4: J5.3, U2.26
IO5: J5.4, U2.29
IO6: J11.5, U5.30
IO7: J11.4, U5.29
IO8: J11.7, U5.37
IO9: J11.3, U5.26
IO10: R13.1, U5.28
IO11: J18.5, U9.10
IO12: J18.4, U9.12
IO13: J17.6, U9.31
IO14: J17.5, U9.30
IO15: J17.4, U9.29
IO16: J17.7, U9.37
IO17: R3.1, U2.28
IO18: J5.5, U2.30
IO19: J5.6, U2.31
IO20: J17.3, U9.26
IO21: R22.1, U9.28
IO22: J24.5, U13.10
IO23: J5.7, U2.37
IO24: J24.4, U13.12
IO25: J4.5, U2.10
IO26: J23.6, U13.31
IO27: J4.4, U2.12
IO28: J23.5, U13.30
IO29: J23.4, U13.29
IO30: J23.7, U13.37
IO31: J23.3, U13.26
IO32: R31.1, U13.28
IO33: J30.5, U17.10
IO34: J30.4, U17.12
IO35: J29.6, U17.31
IO36: J29.5, U17.30
IO37: J29.4, U17.29
IO38: J29.7, U17.37
IO39: J29.3, U17.26
IO40: R40.1, U17.28
IO41: J36.5, U21.10
IO42: J36.4, U21.12
IO43: J35.6, U21.31
IO44: J35.5, U21.30
IO45: J35.4, U21.29
IO46: J35.7, U21.37
IO47: J35.3, U21.26
IO48: R49.1, U21.28
IO49: J42.5, U25.10
IO50: J42.4, U25.12
IO51: J41.6, U25.31
IO52: J41.5, U25.30
IO53: J41.4, U25.29
IO54: J41.7, U25.37
IO55: J41.3, U25.26
IO56: R58.1, U25.28
IO57: J48.5, U29.10
IO58: J48.4, U29.12
IO59: J47.6, U29.31
IO60: J47.5, U29.30
IO61: J47.4, U29.29
IO62: J47.7, U29.37
IO63: J47.3, U29.26
IO64: R67.1, U29.28
IO65: J54.5, U33.10
IO66: J54.4, U33.12
IO67: J53.6, U33.31
IO68: J53.5, U33.30
IO69: J53.4, U33.29
IO70: J53.7, U33.37
IO71: J53.3, U33.26
IO72: R76.1, U33.28
IO73: J60.5, U37.10
IO74: J60.4, U37.12
IO75: J59.6, U37.31
IO76: J59.5, U37.30
IO77: J59.4, U37.29
IO78: J59.7, U37.37
IO79: J59.3, U37.26
IO80: R85.1, U37.28
IO81: J66.5, U41.10
IO82: J66.4, U41.12
IO83: J65.6, U41.31
IO84: J65.5, U41.30
IO85: J65.4, U41.29
IO86: J65.7, U41.37
IO87: J65.3, U41.26
IO88: R94.1, U41.28
IO89: J72.5, U45.10
IO90: J72.4, U45.12
IO91: J71.6, U45.31
IO92: J71.5, U45.30
IO93: J71.4, U45.29
IO94: J71.7, U45.37
IO95: J71.3, U45.26
IO96: R103.1, U45.28
MISO: J4.2, U2.14, U4.MISO
MISO1: J12.2, U5.14, U6.MISO
MISO2: J18.2, U9.14, U10.MISO
MISO3: J24.2, U13.14, U14.MISO
MISO4: J30.2, U17.14, U18.MISO
MISO5: J36.2, U21.14, U22.MISO
MISO6: J42.2, U25.14, U26.MISO
MISO7: J48.2, U29.14, U30.MISO
MISO8: J54.2, U33.14, U34.MISO
MISO9: J60.2, U37.14, U38.MISO
MISO10: J66.2, U41.14, U42.MISO
MISO11: J72.2, U45.14, U46.MISO
MOSI: J4.1, U2.16, U4.MOSI
MOSI1: J12.1, U5.16, U6.MOSI
MOSI2: J18.1, U9.16, U10.MOSI
MOSI3: J24.1, U13.16, U14.MOSI
MOSI4: J30.1, U17.16, U18.MOSI
MOSI5: J36.1, U21.16, U22.MOSI
MOSI6: J42.1, U25.16, U26.MOSI
MOSI7: J48.1, U29.16, U30.MOSI
MOSI8: J54.1, U33.16, U34.MOSI
MOSI9: J60.1, U37.16, U38.MOSI
MOSI10: J66.1, U41.16, U42.MOSI
MOSI11: J72.1, U45.16, U46.MOSI
unnamed: D1.C, R2.2
unnamed: D2.A, R3.2
unnamed: J2.FEED, JP1.1
unnamed: Q2.5, R11.2
unnamed: Q2.2, R12.2
unnamed: D3.A, R13.2
unnamed: D4.C, R14.2
unnamed: J9.FEED, JP2.1
unnamed: Q3.5, R20.2
unnamed: Q1.5, R7.2
unnamed: Q3.2, R21.2
unnamed: Q1.2, R8.2
unnamed: D5.A, R22.2
unnamed: D6.C, R23.2
unnamed: J15.FEED, JP3.1
unnamed: Q4.5, R29.2
unnamed: Q4.2, R30.2
unnamed: D7.A, R31.2
unnamed: D8.C, R32.2
unnamed: J21.FEED, JP4.1
unnamed: Q5.5, R38.2
unnamed: Q5.2, R39.2
unnamed: D9.A, R40.2
unnamed: D10.C, R41.2
unnamed: J27.FEED, JP5.1
unnamed: Q6.5, R47.2
unnamed: Q6.2, R48.2
unnamed: D11.A, R49.2
unnamed: D12.C, R50.2
unnamed: J33.FEED, JP6.1
unnamed: Q7.5, R56.2
unnamed: Q7.2, R57.2
unnamed: D13.A, R58.2
unnamed: D14.C, R59.2
unnamed: J39.FEED, JP7.1
unnamed: Q8.5, R65.2
unnamed: Q8.2, R66.2
unnamed: D15.A, R67.2
unnamed: D16.C, R68.2
unnamed: J45.FEED, JP8.1
unnamed: Q9.5, R74.2
unnamed: Q9.2, R75.2
unnamed: D17.A, R76.2
unnamed: D18.C, R77.2
unnamed: J51.FEED, JP9.1
unnamed: Q10.5, R83.2
unnamed: Q10.2, R84.2
unnamed: D19.A, R85.2
unnamed: D20.C, R86.2
unnamed: J57.FEED, JP10.1
unnamed: Q11.5, R92.2
unnamed: Q11.2, R93.2
unnamed: D21.A, R94.2
unnamed: D22.C, R95.2
unnamed: J63.FEED, JP11.1
unnamed: Q12.5, R101.2
unnamed: Q12.2, R102.2
unnamed: D23.A, R103.2
unnamed: D24.C, R104.2
unnamed: J69.FEED, JP12.1
RESET: C2.1, J4.6, Q1.3, R1.1, S1.3, S1.4, U2.3
RESET1: C13.1, J12.6, Q2.3, R10.1, S3.3, S3.4, U5.3
RESET2: C20.1, J18.6, Q3.3, R19.1, S5.3, S5.4, U9.3
RESET3: C27.1, J24.6, Q4.3, R28.1, S7.3, S7.4, U13.3
RESET4: C34.1, J30.6, Q5.3, R37.1, S9.3, S9.4, U17.3
RESET5: C41.1, J36.6, Q6.3, R46.1, S11.3, S11.4, U21.3
RESET6: C48.1, J42.6, Q7.3, R55.1, S13.3, S13.4, U25.3
RESET7: C55.1, J48.6, Q8.3, R64.1, S15.3, S15.4, U29.3
RESET8: C62.1, J54.6, Q9.3, R73.1, S17.3, S17.4, U33.3
RESET9: C69.1, J60.6, Q10.3, R82.1, S19.3, S19.4, U37.3
RESET10: C76.1, J66.6, Q11.3, R91.1, S21.3, S21.4, U41.3
RESET11: C83.1, J72.6, Q12.3, R100.1, S23.3, S23.4, U45.3
RFM_CS: U2.27, U4.NSS
RFM_CS1: U5.27, U6.NSS
RFM_CS2: U9.27, U10.NSS
RFM_CS3: U13.27, U14.NSS
RFM_CS4: U17.27, U18.NSS
RFM_CS5: U21.27, U22.NSS
RFM_CS6: U25.27, U26.NSS
RFM_CS7: U29.27, U30.NSS
RFM_CS8: U33.27, U34.NSS
RFM_CS9: U37.27, U38.NSS
RFM_CS10: U41.27, U42.NSS
RFM_CS11: U45.27, U46.NSS
RFM_DIO1/1: U5.9, U6.DIO1
RFM_DIO1/2: U9.9, U10.DIO1
RFM_DIO1/3: U13.9, U14.DIO1
RFM_DIO1/4: U17.9, U18.DIO1
RFM_DIO1/5: U21.9, U22.DIO1
RFM_DIO1/6: U25.9, U26.DIO1
RFM_DIO1/7: U29.9, U30.DIO1
RFM_DIO1/8: U33.9, U34.DIO1
RFM_DIO1/9: U37.9, U38.DIO1
RFM_DIO1/10: U41.9, U42.DIO1
RFM_DIO1/11: U45.9, U46.DIO1
RFM_DIO1/33: U2.9, U4.DIO1
RFM_DIO2/1: U5.8, U6.DIO2
RFM_DIO2/2: U9.8, U10.DIO2
RFM_DIO2/3: U13.8, U14.DIO2
RFM_DIO2/4: U17.8, U18.DIO2
RFM_DIO2/5: U21.8, U22.DIO2
RFM_DIO2/6: U25.8, U26.DIO2
RFM_DIO2/7: U29.8, U30.DIO2
RFM_DIO2/8: U33.8, U34.DIO2
RFM_DIO2/9: U37.8, U38.DIO2
RFM_DIO2/10: U41.8, U42.DIO2
RFM_DIO2/11: U45.8, U46.DIO2
RFM_DIO2/32: U2.8, U4.DIO2
RFM_INT/1: U5.11, U6.DIO0
RFM_INT/2: U9.11, U10.DIO0
RFM_INT/3: U13.11, U14.DIO0
RFM_INT/4: U17.11, U18.DIO0
RFM_INT/5: U21.11, U22.DIO0
RFM_INT/6: U25.11, U26.DIO0
RFM_INT/7: U29.11, U30.DIO0
RFM_INT/8: U33.11, U34.DIO0
RFM_INT/9: U37.11, U38.DIO0
RFM_INT/10: U41.11, U42.DIO0
RFM_INT/11: U45.11, U46.DIO0
RFM_INT/26: U2.11, U4.DIO0
RFM_RST: R4.1, U4.!RESET
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

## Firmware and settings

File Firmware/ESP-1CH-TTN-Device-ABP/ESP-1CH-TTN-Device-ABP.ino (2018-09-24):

/*
  Single-Channel TTN ABP Device
  By: Jim Lindblom
  SparkFun Electronics
  Date: July 31, 2018
  License: This code is public domain but you buy me a beer if you use this and we meet someday (Beerware license).
  Feel like supporting our work? Buy a board from SparkFun!

  https://sparkle.sparkfun.com/sparkle/storefront_products/14893

  This example demonstrates how to use the SparkX ESP32 LoRa 1-CH Gateway as a LoRaWAN device.
  It is configured to transmit on a single channel -- making it compatible with the same board
  set up as a gateway.

  Library Dependencies:
  arduino-lmic: https://github.com/mcci-catena/arduino-lmic

  To use the example, ensure that you've first configured the arduino-lmic library as required.
  Then create an application and device on the Things Network. Configure it for ABP activation.
  Then copy the NETWORK SESSION KEY, APP SESSION KEY, and DEVICE ADDRESS into the global variables
  towards the top of this sketch.

  Once uploaded, press the "0" button to trigger a LoRa send. The device will send "Hello, World"
  on the set frequency, hoping your gateway hears it.

  This example is based on ttn-abp by: Thomas Telkamp and Matthijs Kooijman
*/

// Include the arduino-lmic library:
#include <lmic.h>
#include <hal/hal.h>
#include <SPI.h>

// Below sets the trigger for sending a new message to a gateway.
// Either or both can be enabled (in which case pressing the button will restart the timer)
#define SEND_BY_BUTTON 1  // Send a message when button "0" is pressed
#define SEND_BY_TIMER 1 // Send a message every TX_INTERVAL seconds

// LoRaWAN NwkSKey, network session key
// This is the default Semtech key, which is used by the early prototype TTN
// network.
static const PROGMEM u1_t NWKSKEY[16] = { PASTE_NWKSKEY_KEY_HERE };

// LoRaWAN AppSKey, application session key
// This is the default Semtech key, which is used by the early prototype TTN
// network.
static const u1_t PROGMEM APPSKEY[16] = { PASTE_APPSKEY_KEY_HERE };

// LoRaWAN end-device address (DevAddr)
static const u4_t DEVADDR = 0xPASTE_DEV_ADDR_HERE;

// These callbacks are only used in over-the-air activation, so they are
// left empty here (we cannot leave them out completely unless
// DISABLE_JOIN is set in config.h, otherwise the linker will complain).
void os_getArtEui (u1_t* buf) { }
void os_getDevEui (u1_t* buf) { }
void os_getDevKey (u1_t* buf) { }

static uint8_t mydata[] = "Hello, world!";
static osjob_t sendjob;

// Pin mapping for the SparkX ESP32 LoRa 1-CH Gateway
const lmic_pinmap lmic_pins = {
  .nss = 16,
  .rxtx = LMIC_UNUSED_PIN,
  .rst = 5,
  .dio = {26, 33, 32},
};

// If send-by-timer is enabled, define a tx interval
#ifdef SEND_BY_TIMER
#define TX_INTERVAL 60 // Message send interval in seconds
#endif

// State machine event handler
void onEvent (ev_t ev) {
  Serial.print(os_getTime());
  Serial.print(": ");
  switch (ev) {
    case EV_SCAN_TIMEOUT:
      Serial.println(F("EV_SCAN_TIMEOUT"));
      break;
    case EV_BEACON_FOUND:
      Serial.println(F("EV_BEACON_FOUND"));
      break;
    case EV_BEACON_MISSED:
      Serial.println(F("EV_BEACON_MISSED"));
      break;
    case EV_BEACON_TRACKED:
      Serial.println(F("EV_BEACON_TRACKED"));
      break;
    case EV_JOINING:
      Serial.println(F("EV_JOINING"));
      break;
    case EV_JOINED:
      Serial.println(F("EV_JOINED"));
      break;
    case EV_RFU1:
      Serial.println(F("EV_RFU1"));
      break;
    case EV_JOIN_FAILED:
      Serial.println(F("EV_JOIN_FAILED"));
      break;
    case EV_REJOIN_FAILED:
      Serial.println(F("EV_REJOIN_FAILED"));
      break;
    case EV_TXCOMPLETE:
      digitalWrite(LED_BUILTIN, LOW); // Turn off LED after send is complete
      Serial.println(F("EV_TXCOMPLETE (includes waiting for RX windows)"));
      if (LMIC.txrxFlags & TXRX_ACK)
        Serial.println(F("Received ack"));
      if (LMIC.dataLen) {
        Serial.println(F("Received "));
        Serial.println(LMIC.dataLen);
        Serial.println(F(" bytes of payload"));
      }
#ifdef SEND_BY_TIMER
      // Schedule the next transmission
      os_setTimedCallback(&sendjob, os_getTime() + sec2osticks(TX_INTERVAL), do_send);
#endif
      break;
    case EV_LOST_TSYNC:
      Serial.println(F("EV_LOST_TSYNC"));
      break;
    case EV_RESET:
      Serial.println(F("EV_RESET"));
      break;
    case EV_RXCOMPLETE:
      // data received in ping slot
      Serial.println(F("EV_RXCOMPLETE"));
      break;
    case EV_LINK_DEAD:
      Serial.println(F("EV_LINK_DEAD"));
      break;
    case EV_LINK_ALIVE:
      Serial.println(F("EV_LINK_ALIVE"));
      break;
    default:
      Serial.println(F("Unknown event"));
      break;
  }
}

// Transmit data from mydata
void do_send(osjob_t* j) {
  // Check if there is not a current TX/RX job running
  if (LMIC.opmode & OP_TXRXPEND) {
    Serial.println(F("OP_TXRXPEND, not sending"));
  } else {
    digitalWrite(LED_BUILTIN, HIGH); // Turn on LED while sending
    // Prepare upstream data transmission at the next possible time.
    LMIC_setTxData2(1, mydata, sizeof(mydata) - 1, 0);
    Serial.println(F("Packet queued"));
  }
}

void setup() {
  Serial.begin(115200);

  // Set button pin as input
#ifdef SEND_BY_BUTTON
  pinMode(0, INPUT);
#endif
  // Configure built-in LED -- will illuminate when sending
  pinMode(LED_BUILTIN, OUTPUT);
  digitalWrite(LED_BUILTIN, LOW);

  // LMIC init
  os_init();
  // Reset the MAC state. Session and pending data transfers will be discarded.
  LMIC_reset();

  // Set static session parameters. Instead of dynamically establishing a session
  // by joining the network, precomputed session parameters are be provided.
  uint8_t appskey[sizeof(APPSKEY)];
  uint8_t nwkskey[sizeof(NWKSKEY)];
  memcpy_P(appskey, APPSKEY, sizeof(APPSKEY));
  memcpy_P(nwkskey, NWKSKEY, sizeof(NWKSKEY));
  LMIC_setSession (0x1, DEVADDR, nwkskey, appskey);

#if defined(CFG_eu868) // EU channel setup
  // Set up the channel used by the Things Network and compatible with
  // our gateway.
  // Setting up channels should happen after LMIC_setSession, as that
  // configures the minimal channel set.
  LMIC_setupChannel(0, 868100000, DR_RANGE_MAP(DR_SF12, DR_SF7),  BAND_CENTI);      // g-band
#elif defined(CFG_us915) // US channel setup
  // Instead of using selectSubBand, which will cycle through a sub-band of 8
  // channels. We'll configure the device to only use one frequency.
  // First disable all sub-bands
  for (int b = 0; b < 8; ++b) {
    LMIC_disableSubBand(b);
  }
  // Then enable the channel(s) you want to use
  //LMIC_enableChannel(8); // 903.9 MHz
  LMIC_enableChannel(17);
#endif

  // Disable link check validation
  LMIC_setLinkCheckMode(0);

  // TTN uses SF9 for its RX2 window.
  LMIC.dn2Dr = DR_SF9;

  // Set data rate and transmit power for uplink (note: txpow seems to be ignored by the library)
  LMIC_setDrTxpow(DR_SF7, 14);

  // Start job -- Transmit a message on begin
  do_send(&sendjob);
}

void loop() {
  os_runloop_once();
#ifdef SEND_BY_BUTTON
  if (digitalRead(0) == LOW) {
    while (digitalRead(0) == LOW) ;
    do_send(&sendjob);
  }
#endif
}

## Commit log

2018-09-26 almost ready for reds design review
    [esp32_lora_gateway-Panel.brd]
2018-09-26 Reds review
    [Board_Design_Checklist.xls, Board_Design_Checklist_ESP32 LoRa 1 Channel Gateway_v1.xls, Formate.xls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]
2018-09-26 Halfway through design review changes
    [ESP32_LoRa_1_Channel_Gateway.brd, ESP32_LoRa_1_Channel_Gateway.sch, esp32_lora_gateway.brd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]
2018-09-27 Made changes from REDS review pt 1
    [ESP32_LoRa_1_Channel_Gateway.brd, ESP32_LoRa_1_Channel_Gateway.sch]
2018-09-27 Ready for followup
    [Board_Design_Checklist_ESP32 LoRa 1 Channel Gateway_v1.xls, ESP32_LoRa_1_Channel_Gateway.brd, ESP32_LoRa_1_Channel_Gateway.sch]
2018-09-27 Moved rfm95 pin1 indicator
    [ESP32_LoRa_1_Channel_Gateway.brd, ESP32_LoRa_1_Channel_Gateway.sch]
2018-09-27 Moved CC atribution
    [ESP32_LoRa_1_Channel_Gateway.brd]
2018-09-28 Moved LEDs and silk
    [ESP32_LoRa_1_Channel_Gateway.brd]
2018-09-28 Some changes from design review
    [ESP32_LoRa_1_Channel_Gateway.brd, ESP32_LoRa_1_Channel_Gateway.sch]
2018-09-28 Made small fixes
    [Board_Design_Checklist_ESP32 LoRa 1 Channel Gateway_v1.xls, Board_Design_Checklist_ESP32 LoRa 1 Channel Gateway_v10.xls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]
2018-10-03 Fixed checklist issues
    [ESP32_LoRa_1_Channel_Gateway.brd, ESP32_LoRa_1_Channel_Gateway.sch]
2018-10-03 Fixed up ASM layers
    [ESP32_LoRa_1_Channel_Gateway.brd]
2018-10-05 Fixed U.FL location (cleared away form 0603 package)
    [ESP32_LoRa_1_Channel_Gateway.brd]
2018-10-05 panel v10 created
    [14119-ESP32_LoRa_1_Channel_Gateway-Panel.GBL, 14119-ESP32_LoRa_1_Channel_Gateway-Panel.GBO, 14119-ESP32_LoRa_1_Channel_Gateway-Panel.GBP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]
2018-10-05 added gerber zip file
2018-11-14 Add eagle gitignore, remove Eagle backup files
    [ESP32_LoRa_1_Channel_Gateway.GBL, ESP32_LoRa_1_Channel_Gateway.GBO, ESP32_LoRa_1_Channel_Gateway.GBP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]
2018-11-15 Move panel files (.brd and gerbers) to Hardware sub-folder
    [14119-ESP32_LoRa_1_Channel_Gateway-Panel.GBL, 14119-ESP32_LoRa_1_Channel_Gateway-Panel.GBO, 14119-ESP32_LoRa_1_Channel_Gateway-Panel.GBP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]
2021-03-19 Updated attributes
    [ESP32_LoRa_1_Channel_Gateway.brd, ESP32_LoRa_1_Channel_Gateway.sch]
2021-04-07 Updated Momentary Switches
    Updated Switches from SWCH-13065 to SWCH-15606
    [ESP32_LoRa_1_Channel_Gateway.brd, ESP32_LoRa_1_Channel_Gateway.sch]
2023-02-10 Update ESP32 Datasheet

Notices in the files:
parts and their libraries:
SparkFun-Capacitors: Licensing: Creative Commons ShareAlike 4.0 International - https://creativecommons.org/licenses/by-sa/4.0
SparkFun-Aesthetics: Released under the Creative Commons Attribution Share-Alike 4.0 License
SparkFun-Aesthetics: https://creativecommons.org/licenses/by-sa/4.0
